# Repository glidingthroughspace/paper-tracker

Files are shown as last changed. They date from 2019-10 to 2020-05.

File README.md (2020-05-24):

# Paper Tracker

The Paper Tracker is a system for tracking documents inside buildings. It uses WiFi Access Points to
calculate the documents' current location and links it to the current step in its workflow.

It consists of a hardware tracker, a backend server and a mobile application for Android and iOS.

## Getting started

You need to get a Tracker (the hardware device), install the backend application on a server and
download the app for your phone.

### The Server

Download the pre-built server application for
[Linux](https://github.com/glidingthroughspace/paper-tracker/releases/latest/download/paper-tracker_linux_x86_64),
place it on a server and run it. It will listen for HTTP requests on port `8080`, so go ahead and
visit `your-server.domain:8080`, which links all the other downloads you'll need.

Note that the server also listens for CoAP requests on port `5688`, so you might need to allow UDP
requests to that port in your servers firewall.

You could also install [Go](https://go.dev) and build the server yourself by running `make` or `make
run` in the `server/` directory. This way, you can run the server on Windows and MacOS as well.

Additionally there is a Dockerfile available in the `server` folder. The docker also uses `8080` as http and `5688` as CoAP port default.
The config file and database are located in the `/config` folder.

For individually configuring the server, you can use the `config_example.toml` as template and rename it to `config.toml`.
Information about the available parameters are available through the `--help` command of the server executable.

### The Tracker

The tracker is built out of a [TinyPICO](https://tinypico.com), which is an ESP32-based development
board and a LiPo battery.
If you have a Tracker, download the Firmware Flasher for
[Linux](https://github.com/glidingthroughspace/paper-tracker/releases/latest/download/flasher-Linux.zip)
or
[Windows](https://github.com/glidingthroughspace/paper-tracker/releases/latest/download/flasher-Windows.zip),
extract the ZIP file and run the flasher application. It will ask you for WiFi credentials and a
path to the firmware directory, which is bundled in the given ZIP file. For flashing, you'll need to
have [PlatformIO Core](https://platformio.org) installed.
After flashing the tracker, it will automatically connect to the server, if the given WiFi
credentials are correct.

### The App

The app is written in Flutter and thus is available for Android and iOS. However, prebuilt apps only
exist for Android. You can download them from Github Releases, an explanation of which download
you'll need is given on the server's download page.

# Licensing

This repository contains multiple sub-projects (folders), each of which has its
own `LICENSE` file, denoting which license is used for the specific
sub-project. The TL;DR is: Code is licensed under the [Apache
2.0](https://www.apache.org/licenses/LICENSE-2.0.html) license, the paper
(everything in the `paper/` directory) is under the
[CC-BY-NC-SA 4.0](http://creativecommons.org/licenses/by-nc-sa/4.0/)
license.

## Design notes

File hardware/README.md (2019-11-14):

# Hardware

This directory contains the firmware for the tracker devices as well as everything else related to
the hardware like CAD files or analyses.

See the README files in each directory for more information.

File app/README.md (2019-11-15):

# paper_tracker

Frontend application for the paper-tracker project

## Getting Started

This project is a starting point for a Flutter application.

A few resources to get you started if this is your first Flutter project:

- [Lab: Write your first Flutter app](https://flutter.dev/docs/get-started/codelab)
- [Cookbook: Useful Flutter samples](https://flutter.dev/docs/cookbook)

For help getting started with Flutter, view our
[online documentation](https://flutter.dev/docs), which offers tutorials,
samples, guidance on mobile development, and a full API reference.

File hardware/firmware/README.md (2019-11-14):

# Tracker Firmware

This directory contains the firmware for the paper tracker hardware devices.
It is built using [PlatformIO](https://platformio.org), which makes it simple to resolve
dependencies and build it in a CI workflow.

Since the hardware is supposed to be based on an ESP8285 board, this is one of the build targets.
Currently however, we're developing the firmware on the 100% compatible ESP8266 board, namely a
WeMos D1 mini, which is the default build target.

We build the firmware using `make`, since the PlatformIO commands can get quite long. The following
targets are available:

* `build`: Build for the _current_ MCU platform. You can set the platform in the
  `PLATFORM` variable (either `d1_mini` or `esp8285`)
* `build-all`: Build for all defined platforms. This is used in CI
* `upload`: Uploads the code to the current platform. Configure the serial port to use in the
  `SERIALPORT` variable (defaults to `/dev/ttyUSB0`)
* `monitor`: Starts the serial monitor on the given serial port
* `run`: Build and upload the code, start the serial monitor

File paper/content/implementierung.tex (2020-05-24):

\chapter{Implementierung} \label{chap:implementierung}

\section{Hardware und Firmware}

Im Folgenden wird erläutert, wie der Tracker hinsichtlich der verwendeten Hardware und der
entsprechenden Firmware implementiert wurde.

\subsection{Verwendete Technologien}\label{sec:hardware-used-technologies}

Als Mikrocontrollerplattform wurde die sogenannte \enquote{TinyPICO}-Plattform gewählt. Nach eigener
Aussage handelt es sich dabei um die kleinste vorgefertigte Entwicklungsplattform basierend auf
Mikrocontrollern vom Typ ESP32. (vgl. \cite{tinypico2020}) Dieser Aspekt ist für die Erfüllung von \ref{nf:klein} wichtig.
Dieser Mikrocontroller wurde gewählt, da er alle benötigten Funktionen wie beispielsweise \gls{WLAN}
bereits über ein \gls{API} bereitstellt.

Die TinyPICO-Entwicklungsplattform stellt neben dem Mikrocontroller weitere Hardware bereit, so sind
unter anderem
eine Stromversorgung über \gls{USB} sowie Lithium-Polymer-\gls{Akku}, ein Übersetzer von \gls{USB}
zu \gls{UART} zur Programmierung des Mikrocontrollers und eine Vollspektrum-\gls{LED} verbaut.
Ein weiterer Vorteil ist das bereits integrierte Ladesystem, welches einen angeschlossenen
Lithium-Polymer-\gls{Akku} automatisch auflädt, sobald der Tracker über \gls{USB} mit einer
Stromquelle verbunden wird. Außerdem können über das Ladesystem der aktuelle Ladezustand und die
Spannung des \glspl{Akku} abgefragt werden, was für die Erfüllung von \ref{fa:benachrichtigung}
unabdingbar ist.

Die Firmware wurde in der Programmiersprache C++ auf Basis des Arduino-Frameworks erstellt. Dieses
Framework wurde gewählt, da es auf vielen Plattformen, wie auch dem ESP32 lauffähig ist, weit
verbreitet ist und somit viele Bibliotheken für das Framework existieren.

Das \enquote{Flasher}-Tool zum Programmieren und Konfigurieren der Firmware wurde in Python
entwickelt.
Der Grund dafür liegt in der Möglichkeit sehr schnell und simpel sowohl ein Programm als auch eine \gls{GUI}
programmieren zu können.
Dies wird durch die Bibliothek \enquote{PySimpleGUI} ermöglicht, die lediglich mit einer groben Layout-Beschreibung
eine Oberfläche zusammenstellt.
Alle weiteren benötigten Bibliotheken sind in der Python-Standardbibliothek enthalten.
Vor allem ist hierbei die \enquote{multiprocessing}-Bibliothek wichtig, mit welcher andere Programme aufgerufen werden können.
Um aus dem enstandenen Python-Skript eine ausführbare Datei für die verbreitesten Betriebssysteme zu erstellen, wird \enquote{PyInstaller} verwendet.
Die daraus enstehende Datei beinhaltet bis auf das PlatformIO-Tooling alle benötigten Ressourcen.

\subsection{Flasher}
Aufgrund der angestrebten Einfachheit dieses Programmes besteht es aus insgesamt nur drei Dateien.
Der Hauptbestandteil des Flashers ist das eigentliche Python-Skript.
Zusätzlich wird die Datei \enquote{requirements.txt} benötigt, welche alle Bibliotheken für den
Bibliotheksmanager \enquote{pip} auflistet.
In dieser Datei sind lediglich, wie oben erwähnt, \enquote{pysimplegui} und \enquote{pyinstaller} aufgeführt.
Die dritte und letzte Datei ist ein \enquote{Makefile}, welches einige Befehle zum Installieren der Bibliotheken,
Ausführen des Skripts oder Erstellen der ausführbaren Datei bereitstellt.

Das Skript selbst beginnt nach dem Importieren der benötigten Bibliotheken mit dem Parsen der
Kommandozeilenargumente.
Möglich ist nur das Argument \texttt{--keep-credentials}.
Das Skript erzeugt eine Datei, in welcher die Zugangsdaten für das vom Tracker zu verwendende
\gls{WLAN}-Netzwerk sowie weitere potentiell sensitive Informationen enthalten sind. Im
Standardfall wird diese Datei nach dem Erstellen der Firmware und der Programmierung des Trackers
gelöscht. Ist das Kommandozeilenargument \texttt{--keep-credentials} gegeben, wird die Datei nach
erfolgreichem Abschluss des Programmiervorganges nicht gelöscht, was vor allem in der
Entwicklungsphase der Software vorteilhaft ist.

Weiter werden einige Konstanten definiert.
Diese sind zum einen der Titel des Programm-Fensters und einige sogenannte \enquote{Keys},
die eindeutig bestimmte Elemente der \gls{GUI} identifizieren.

Nach den Konstanten werden drei Funktionen definiert, die die eigentliche Logik des Flashers beinhalten.
Zuerst eine Funktion, die alle möglichen Ports, über die ein Tracker programmiert werden kann, auflistet.
Dies wird über ein Aufrufen von PlatformIO ermöglicht: \enquote{pio device list}.

Die nächste Funktion generiert die für die Firmware benötigte Datei mit der Konfiguration des Trackers.
Sie liest ein Template mit Platzhalter-Werten der Datei ein und ersetzt die Platzhalter mit den eingegebenen Werten, die als Parameter übergeben werden.
Nach dem Einsetzen der Werte wird die Datei geschrieben.
Der Pfad, an dem sich die Firmware befindet, ist auch Teil der Werte, die als Parameter übergeben werden.
Zugriff auf einen einzelnen Wert wird über die oben erwähnten konstanten \enquote{Keys} ermöglicht.

In der letzten Funktion wird das Programmieren an sich ausgeführt.
Auch diese Funktion bekommt die eingebenenen Werte als Parameter. Aus diesen wird der ausgewählte Port benötigt.
Mit diesem wird wieder PlatformIO aufgerufen: \enquote{pio run -e tinypico -t upload --upload-port port}.

Vor dem Hauptteil des Skripts werden noch die Layouts für die \gls{GUI} benötigt.
Es werden zwei verschiedene Layouts definiert: Ein Eingabe-Layout und ein Programmier-Layout.
Das Eingabe-Layout ist in \autoref{fig:flasher-input} dargestellt.
Es ist eine Tabelle aus Eingabe-Feldern mit Erklärungen, in denen alle benötigten Konfigurationen eingetragen werden können.
Die Eingabe-Felder selbst sind mit den Keys verknüpft.
Am unteren Teil des Layouts befindet sich ein Button, der das Programmieren startet.

\begin{figure}[htbp]
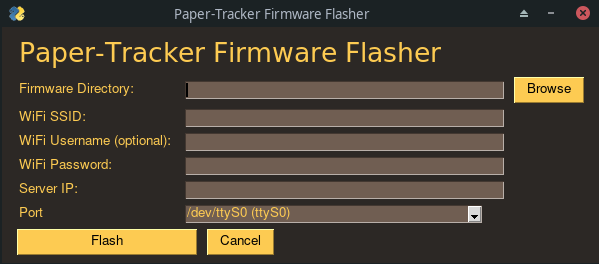
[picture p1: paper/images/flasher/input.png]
	
	\centering
	\caption{Layout des Eingabe-Fensters}
	\label{fig:flasher-input}
\end{figure}

Das Programmier-Layout besteht lediglich aus einem Titel, einem Textfeld und einem Button.
Es ist in \autoref{fig:flasher-flash} dargestellt.
Im Textfeld soll der aktuelle Status angezeigt werden.
Der Button ist zum Schließen des Programms, sobald der Vorgang abgeschlossen ist.

\begin{figure}[htbp]
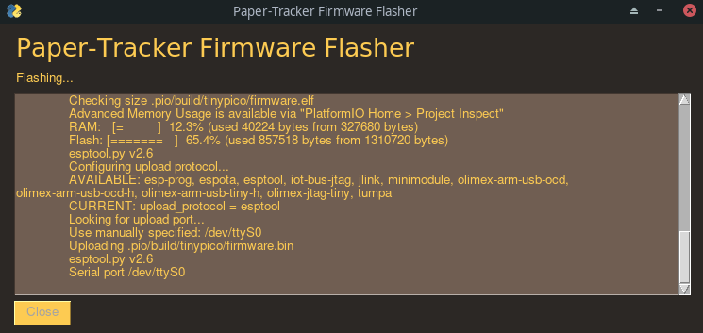
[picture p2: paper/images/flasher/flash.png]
	
	\centering
	\caption{Layout des Programmier-Fensters}
	\label{fig:flasher-flash}
\end{figure}

Im Hauptteil des Skripts wird nun zuerst das Fenster mit dem Eingabe-Layout geöffnet.
Sobald der Button zum Start gedrückt wurde, werden die eingegebenen Werte ausgelesen.
Das Eingabe-Fenster wird geschlossen und das Programmier-Fenster mit dem entsprechendem Layout geöffnet.
Ist dieses offen, wird die Funktion zum Generieren der Konfigurationsdatei und die Funktion zum Programmieren des Trackers aufgerufen.
Im Textfeld des Layouts werden diese Schritte entsprechend dokumentiert.
Auch die Ausgabe des Programmierens wird im Textfeld abgebildet.
Nach dem Programmieren wird, je nach Kommandozeilenargument, die generierte Datei gelöscht.
Nun kann das Fenster und damit das gesamte Programm über den Schließen-Button geschlossen werden.

Tritt während dieses gesamten Vorgang ein Fehler auf, wird dieser entsprechend aufgefangen und die Fehlermeldung im Textfeld angezeigt.
Das Löschen der generierten Datei wird auch im Fehlerfall ausgeführt.

\subsection{Akkumulator}

Um \ref*{nf:akku} zu erfüllen, muss ein \gls{Akku} mit entsprechend großer Kapazität gewählt werden.
Zu diesem Zweck wird die Laufzeit des Trackers mit einem \gls{Akku} mit einer Kapazität von $850
mAh$ in verschiedenen Szenarien gemessen. Bei den Tests befindet sich der Tracker dauerhaft im
\enquote{Tracking}-Status, meldet also immer wieder die aktuelle Position an den Server. Dieser
Zustand wurde gewählt, da hier der Stromverbrauch am größten ist. Zu beachten ist jedoch, dass der
Tracker pro Zyklus (Aufwachen und Abholen eines Kommandos) immer nur einmal die \gls{WLAN}-Umgebung an den Server übermittelt. Wie in
\autoref{sec:tracker-lokalisierung} beschrieben, ist dies noch nicht unbedingt ausreichend, um den
Tracker zu lokalisieren.

Im ersten Test, dessen Ergebnis in
\autoref{fig:battery-runtime-quicktrack} in blau zu sehen ist, wurde dabei alle $10$ Sekunden die Position
des Trackers abgefragt.

\begin{figure}[htbp]
	\centering
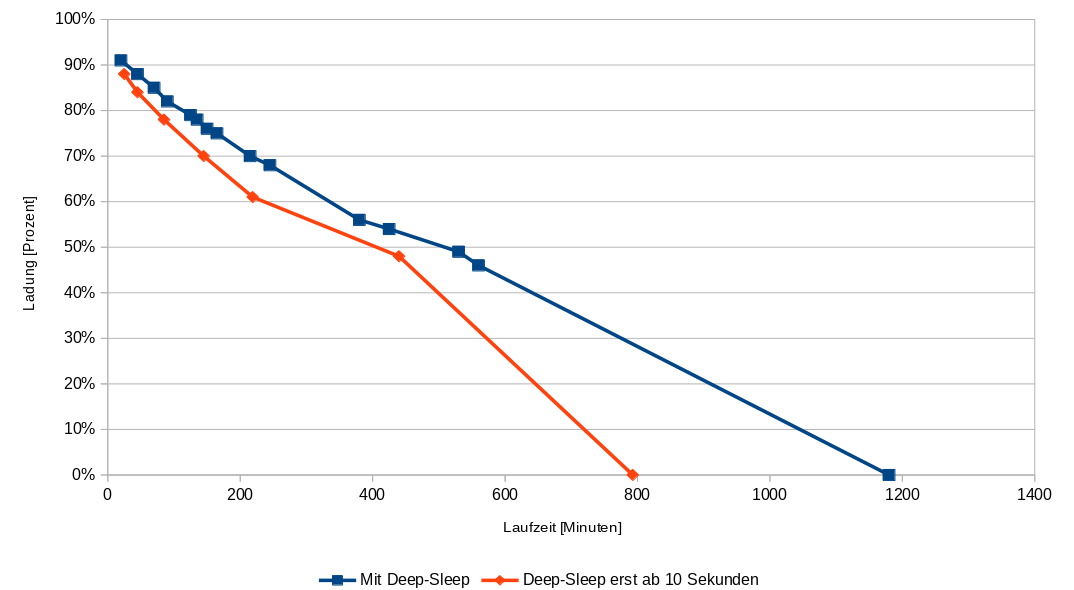
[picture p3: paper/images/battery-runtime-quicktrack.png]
	
	\caption{Akkulaufzeit mit einem Tracking-Intervall von 10 Sekunden}
	\label{fig:battery-runtime-quicktrack}
\end{figure}

Beim ersten Test ist der Tracker nach dem Bearbeiten einer Aufgabe direkt in den \enquote{Deep-Sleep}
übergegangen. Beim zweiten Test (dargestellt in rot) erst dann, wenn die vom Server übermittelte Schlafdauer größer als $10$
Sekunden ist, was in diesem Test nie der Fall war. Wie deutlich zu sehen ist, kann durch das
sofortige Schlafen des Trackers eine um circa $400$ Minuten längere Laufzeit erreicht werden. Es ist
jedoch zu erwarten, dass der Tracker immer länger als $10$ Sekunden schläft, außer beim Einlernen
eines neuen Raumes. Bei dieser Operation ist vor allem die Reaktivität des Trackers wichtig, um
möglichst viele \glspl{AP} mit möglichst vielen Messungen zu erfassen. Daher wird die
Funktionalität, dass der Tracker sich nur in den \enquote{Deep-Sleep} begibt, wenn die Schlafdauer
$10$ Sekunden überschreitet, implementiert und die damit verbundene, geringere Laufzeit in Kauf
genommen.

\begin{figure}[htbp]
	\centering
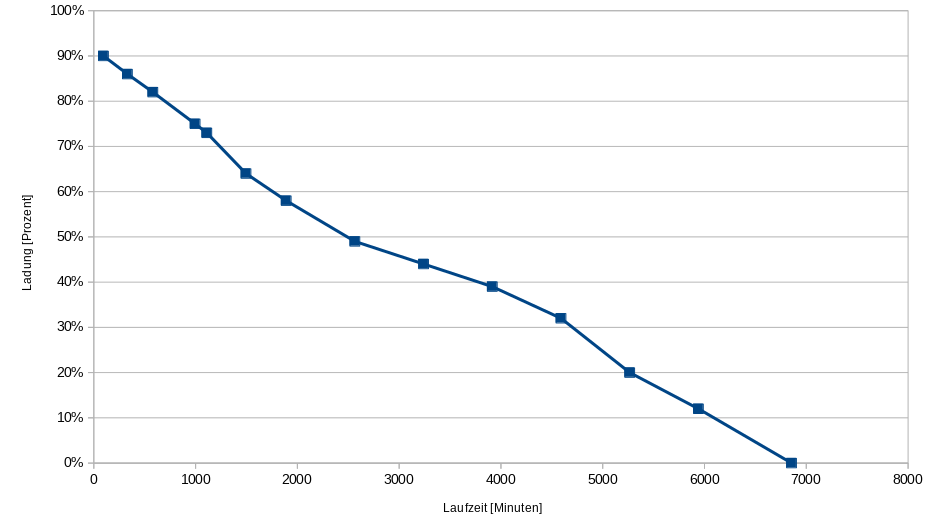
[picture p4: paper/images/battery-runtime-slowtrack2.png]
	
	\caption{Akkulaufzeit mit einem Tracking-Intervall von 60 Sekunden}
	\label{fig:battery-runtime-slowtrack}
\end{figure}

In einem zweiten Szenario ist der Tracker alle $60$ Sekunden aufgewacht, um die aktuelle Position
zu ermitteln. Die Laufzeit des Trackers mit diesen Parametern ist in
\autoref{fig:battery-runtime-slowtrack} zu sehen. Wie zu sehen ist, skaliert die Laufzeit des
Trackers nahezu linear mit der Schlafdauer. Mit einer Schlafdauer von $60$ Sekunden konnte bereits
eine Laufzeit von mehr als 4 Tagen erreicht werden.

Daraus lässt sich schließen, dass sich \ref*{nf:akku} mit einem \gls{Akku} mit einer Kapazität von $850
mAh$ erfüllen lässt, indem der Tracker nicht den gesamten Tag aktiv ist oder das Tracking-Intervall
auf $120$ Sekunden erhöht wird. Da Dokumente üblicherweise nicht den gesamten Tag über getracked
werden müssen, sondern nur in den üblichen Arbeitszeiten, wird die Möglichkeit in den Server
implementiert, ebendiese zu definieren. So kann der Tracker meist den halben Tag inaktiv sein, am
Wochenende muss er gar nicht aufwachen.

\subsection{Sammeln von \glsentryshort{WLAN}-Daten}

Um die aktuelle \gls{WLAN}-Umgebung abzurufen und an den Server zu senden wird primär in das
Arduino-Framework eingebaute Funktionalität genutzt. Die durch das Framework bereitgestellte Klasse
\texttt{WiFi} bietet Methoden zur Abfrage aller \glspl{AP} inclusive deren \gls{BSSID},
\gls{SSID} und \gls{RSSI}.

\begin{lstlisting}[caption={Ausschnit aus der Firmware des Trackers -- Abrufen der \glsentryshort{WLAN}-Netzwerke},label={lst:wlan-firmware}]
std::vector<ScanResult> WIFI::getAllVisibleNetworks() {
  uint8_t visibleNetworkCount = WiFi.scanNetworks();
  std::vector<ScanResult> scanResults(0);
  for (auto i = 0; i < visibleNetworkCount; i++) {
    scanResults.emplace_back(WiFi.RSSI(i), WiFi.BSSIDstr(i), WiFi.SSID(i));
  }
  return scanResults;
}
\end{lstlisting}

In \autoref{lst:wlan-firmware} ist zu sehen, wie die Standardbibliothek genutzt wird. Die hier
erstellte Liste von Scanergebnissen wird, bevor sie zum Server gesendet wird, in mehrere Teile
geteilt. Diese enthalten jeweils fünf Scanergebnisse, damit die in
\autoref{sec:tracker-lokalisierung} beschriebene, maximale Größe eines \gls{UDP}-Paketes nicht
überschritten wird.

Die Arduino-\gls{API} gibt für die \texttt{WiFi.RSSI()}-Funktion an, dass diese eine Angabe in $dBm$
zurückliefert. (vgl. \cite{Arduino2020.1}) Durch diese Standardisierung kann jede
Entwicklungsplattform genutzt werden, die mit dem Arduino-Framework kompatibel ist, ohne dass die
Messung angepasst werden muss.

\subsection{\glsentryshort{API}-Client}

Um sich mit der vom Server angebotenen \gls{CoAP}-\gls{API} zu verbinden, wurde in der Firmware ein
entsprechender Client implementiert. Dieser nutzt eine erweiterte Version der \enquote{CoAP simple
library}\footnote{Original: \url{https://github.com/hirotakaster/CoAP-simple-library}} für die
Arduino-Plattform. Diese implementiert die Kommunikation mit einem \gls{CoAP}-Server, indem sie
Methoden zur Verfügung stellt, um Anfragen an einen Server zu senden und Antworten zu empfangen.

Die Klasse \texttt{APIClient}, welche in der Firmware genutzt wird, um die Kommunkation zu kapseln,
arbeitet mit Callbacks, um Antworten an Anfragen an den Aufrufer zurückzugeben. Dabei wird auch ein
Timeout-Mechanismus implementiert, welcher Anfragen abbricht, wenn für eine gewisse Zeit keine
Antwort empfangen wird. Dadurch wird verhindert, dass aufgrund der volatilen Natur von \gls{UDP} der
Tracker beliebig lange auf Antworten wartet und so sehr schnell den \gls{Akku} entleert.

Zusätzlich kümmert sich der \gls{API}-Client um die Serialisierung und Deserialisierung von
Nutzdaten in das \gls{CBOR}-Format.

\subsection{Serialisierung und Deserialisierung}

Wie in \autoref{par:tracker-schnittstelle} beschrieben, werden Nutzdaten zwischen Server und Tracker
mit \gls{CBOR} codiert ausgetauscht. Dieses Format ist besonders performant und leichtgewichtig und
daher optimal für den Einsatz im \gls{IoT} geeignet. Implementiert wurde ein System zur
Serialisierung und Deserialisierung auf Basis der \enquote{libCBOR}-Bibliothek \footnote{Siehe
\url{https://github.com/ssilverman/libCBOR}}. Das entwickelte System ermöglicht es, sehr schnell und
einfach Entitäten zu \gls{CBOR} zu serialisieren und zu deserialiseren.

\begin{lstlisting}[caption={Beispiel zur Deserialisierung von \glsentryshort{CBOR} mit den
entwickelten Helferklassen},label={lst:cbor-deserialiserung}]
class Command {
private:
	CBORUint16 sleepTimeSec{"sleep_time_sec"};
	CBORUint8 type{"type"};
public:
	bool fromCBOR(uint8_t* buffer, size_t bufferSize) {
		auto cbor = CBORParser(buffer, bufferSize);
		if (!cbor.isWellformedModel()) { return false; }

		while(cbor.advance()) {
			auto key = cbor.findNextKey();
			if (key == nullptr) { continue; }

			if (type.matchesKey(key)) {
				type.deserializeFrom(cbor);
			} else if (sleepTimeSec.matchesKey(key)) {
				sleepTimeSec.deserializeFrom(cbor);
			}
		}

		return true;
	}
};
\end{lstlisting}

So ist in \autoref{lst:cbor-deserialiserung} der vollständige, zur Deserialisierung eines Befehls
vom Server an den Client nötige Code gezeigt. Einzig die Fehlerbehandlung wurde zur
Übersichtlichkeit entfernt. Für die Implementierung der Bibliothek wurden eigene Typen entwickelt,
die Basisdatentypen wiederspiegeln (\texttt{CBORUint8}, \texttt{CBORInt16}, \texttt{CBORString},
...) und die Serialisierung und Deserialisierung in sich kapseln.

\section{Backend-Server}

\subsection{Verwendete Technologien} \label{sec:impl-server-technology}

Die grundlegend verwendete Technologie für den Backend-Server ist die Programmiersprache \enquote{Go}.
Go wurde ausgewählt, da es eine einfach zu verstehende Programmiersprache ist, die optimiert für Server-Anwendungen ist (vgl. \cite{Weigend2019}).
Zudem sind alle am Projekt beteiligten Personen schon mit der Sprache vertraut.

Go stellt eine gute Standardbibliothek zur Verfügung, die an vielen Stellen verwendet wird.
Trotzdem werden zusätzlich einige externe Bibliotheken verwendet.
Diese dienen hauptsächlich dazu, die externen Schnittstellen (\gls{HTTP} und \gls{CoAP}) mit den dazugehörigen Datenformaten zur Verfügung zu stellen.
Auch werden Bibliotheken für ein einfacheres Testing verwendet.

Im Folgenden sind die verwendeten Bibliotheken aufgelistet:
\begin{description}
	\item[pflag (https://github.com/spf13/pflag)] \hfill \\
		\enquote{pflag} wird zum Angeben und Parsen von Kommandozeilenargumenten verwendet. Es ist kompatibel mit \enquote{viper}.
	\item[viper (https://github.com/spf13/viper)] \hfill \\
		Für die Konfiguration des Servers wird \enquote{viper} verwendet. Es kann Konfigurationen aus \enquote{pflag}, Dateien und mehr einlesen.
	\item[logrus (https://github.com/sirupsen/logrus)] \hfill \\
		\enquote{logrus} ist ein strukturiertes Logging-Tool, das für jegliche Logs innerhalb des Servers verwendet wird.
	\item[gorm (https://github.com/jinzhu/gorm)] \hfill \\
		\enquote{gorm} ist ein \gls{ORM} Framework, das die Datenbankanbindung für den Server zur Verfügung stellt.
	\item[Gin (https://github.com/gin-gonic/gin)] \hfill \\
		\enquote{Gin} ist ein HTTP Framework, das Routing, Parameter-Matching, etc. übernimmt. Zudem kann es standardmäßig \gls{JSON} verstehen.
	\item[go-coap (https://github.com/go-ocf/go-coap)] \hfill \\
		\enquote{go-coap} ist ein \gls{CoAP} Framework, das hauptsächlich das Routing übernimmt. Einige weitere Aufgaben, die z.B. \enquote{Gin} übernimmt, müssen selbst programmiert werden.
	\item[go-codec (https://github.com/ugorji/go)] \hfill \\
		\enquote{go-codec} stellt die Codierung für \gls{CBOR} zur Verfügung.
	\item[now (https://github.com/jinzhu/now)] \hfill \\
		\enquote{now} stellt Hilfsfunktionen für Zeitberechnungen zur Verfügung.
	\item[stats (https://github.com/montanaflynn/stats)] \hfill \\
		\enquote{stats} stellt einige mathematische Funktionalitäten für statistische Berechnungen zur Verfügung.
	\item[xlsx (https://github.com/tealeg/xlsx)] \hfill \\
		Mit \enquote{xlsx} können Dateien im \gls{XLSX} Dateiformat erstellt, bearbeitet und gelesen
		werden. Im Server wird sie für das Erstellen des Excel-Exports genutzt.
	\item[gomail (https://github.com/go-gomail/gomail)] \hfill \\
		\enquote{gomail} wird verwendet, um E-Mails verschicken zu können.
	\item[ginkgo (https://github.com/onsi/ginkgo)] \hfill \\
		Mit \enquote{ginkgo} können Tests in \gls{BDD} Technik geschrieben werden.
	\item[gomega (https://github.com/onsi/gomega)] \hfill \\
		\enquote{gomega} ist eine Matching Library, die zu \enquote{ginkgo} gehört. Sie stellt Vergleiche zwischen erwarteten Werten und tatsächlichen Werten zur Verfügung.
	\item[GoMock (https://github.com/golang/mock)] \hfill \\
		\enquote{GoMock} ist ein Mocking Framework, das für verschiedene Tests verwendet wird.
\end{description}

Als Datenbank wird in Kombination mit \enquote{gorm} eine \enquote{SQLite} verwendet.
Der große Vorteil ist, dass eine SQLite Datenbank eine einfache Datei ist und kein externer Server aufgesetzt werden muss.
Dies vereinfacht vor allem die Entwicklung.
Zum Beispiel ist ein einfaches Zurücksetzen der Daten durch ein Löschen der Datei möglich.

In einem späteren Einsatz des Paper-Trackers können dank der \enquote{gorm} Bibliothek auch andere
Datenbanken verwendet werden, die eher für einen dauerhaften und sichereren Einsatz vorgesehen sind.
Möglich sind dafür \enquote{MySQL}, \enquote{PostgreSQL}, \enquote{Microsoft SQL Server} und wie erwähnt SQLite.
Im Code des Servers muss hierfür lediglich eine erweiterte Konfiguration ermöglicht werden. (vgl. \cite{Jinzhu2020})

\subsection{\glsentryfull{REST}-Schnittstelle}

Die \gls{REST}-Schnittstelle zur Anbindung der App wurde wie in \autoref{par:app-schnittstelle}
beschrieben implementiert.
Dabei wurden alle Endpunkte entsprechend umgesetzt.
Wie in \autoref{sec:impl-server-technology} erwähnt, wird das Gin-Framework als
\gls{HTTP}-Router und zum Serialisieren sowie Deserialisieren der Nutzdaten verwendet.
Das Framework ermöglicht es, für jeden \gls{REST}-Endpunkt, also für jede Kombination aus
\gls{HTTP}-Verb und \gls{URL} eine sogenannte Handler-Funktion zu definieren. Diese wird aufgerufen,
wenn eine Anfrage an die entsprechende Ressource getätigt wird. Die Handler-Funktionen parsen
zunächst die Anfragedaten in entsprechende Go-Strukturen. Im Anschluss werden eine oder mehrere
Manager-Funktionen aufgerufen, welche die Geschäftslogik enthalten. Das Ergebnis dieses Aufrufes
wird dann von der Handler-Funktion in das Zielformat, in diesem Fall \gls{JSON}, serialisiert und an
den Aufrufer gesendet.

\subsection{\glsentryfull{CoAP}-Schnittstelle}

Die \gls{CoAP}-Schnittstelle für die Tracker wurde grundsätzlich wie in
\autoref{par:tracker-schnittstelle} beschrieben implementiert. Es wurde allerdings ein weiterer
Endpunkt hinzugefügt: Über den Pfad \texttt{/tracker/status}, welcher mit dem Verb \texttt{POST}
angesprochen wird, kann der Tracker aktuelle Statuswerte, wie beispielsweise die aktuelle
Akkuladung, an den Server übermitteln. Diese Statuswerte werden bei aktivem Tracking in den
Scanergebnis-Paketen übermittelt. Wenn der Tracker sich jedoch im Leerlauf befindet, sendet der
Server periodisch Status-Kommandos an den Tracker, sodass auch hier der Ladezustand des \gls{Akku}s, sowie
die verbleibende Restladung aktualisiert werden können.

\subsection{Tracker-Lokalisierung} \label{sec:tracker-lokalisierung}

Wie in \autoref{sec:tracking-hardware} beschrieben, wird die Lokalisierung der Tracker mit einem
Score-basierten System durchgeführt.

Dazu werden zunächst Scanergebnisse vom jeweiligen Tracker gesammelt und dann ausgewertet. Da die
Datengröße der Scanergebnisse je nach Anzahl der vom Tracker sichtbaren \gls{WLAN}-Netzwerke zu
groß für ein einzelnes \gls{UDP}-Paket ist\footnote{Im Arduino-Framework gibt es eine
Limitierung von 1446 Bytes für die Größe eines \gls{UDP}-Paketes. (vgl. \cite{Arduino2020})}, wurde
das \gls{API} so gestaltet, dass die Ergebnisse in mehreren Paketen an den Server übermittelt werden
können. Dazu berechnet der Tracker im Voraus, in wie viele Pakete die Scanergebnisse geteilt werden
müssen. Diese Zahl, sowie eine für den Ergebnissatz einheitlicher, zufällig erzeugter \gls{ID} sind
jedem Teilpaket angehängt. So kann der Server erkennen, ob alle Ergebnisse empfangen wurden und
diese dann verwenden. Dass nicht alle Pakete eines Ergebnissatzes beim Server angekommen sind, ist
dadurch erkennbar, dass eine andere \gls{ID} empfangen wird. In diesem Fall werden alle vom
vorherigen Paket empfangenen Scanergebnisse verworfen und die neuen Pakete gespeichert.
\TODO{Das hier kann vielleicht zu CoAP-Schnittstelle verschoben werden}

Sobald ein vollständiger Ergebnissatz empfangen wurde, wird aus diesem ein Score für jeden Raum
ermittelt. Dieser Score ist eine Zahl, deren Wert größer wird, je besser die gemessene
\gls{WLAN}-Umgebung mit der gelernten übereinstimmt.

\begin{lstlisting}[caption={Pseudocode-Beschreibung der Scoring-Funktion},label={lst:scoring},tabsize=2]
# Berechnet den Score für ein Scanergebnis und einen Raum
#
# rssi ist das aktuelle Scanergebnis des Trackers
# room enthält die zuvor gelernten Scandaten
func getScoreForScanResultAndRoom(rssi, room) float {
	score := 0.0
	rssiFactor := math.Abs(rssi / 100.0)

	if rssi <= room.Maximum && rssi >= room.Minimum {
		score += inMinimumMaximumFactor * rssiFactor
	}
	if rssi < room.ThirdQuartile && rssi > room.FirstQuartile {
		score += inQuartilesFactor * rssiFactor
	}
	if isInRange(rssi, room.Mean, rangeForMean) {
		distance := math.Abs(room.Mean - rssi)
		score += math.Abs(distance-rangeForMean) * inMeanRangeFactor * rssiFactor
	}
	if isInRange(rssi, room.Median, rangeForMedian) {
		distance := math.Abs(room.Median - rssi)
		score += math.Abs(distance-rangeForMedian) * inMedianRangeFactor * rssiFactor
	}
	return score
}
\end{lstlisting}

\autoref{lst:scoring} zeigt einen Teil des Scoring-Algorithmus. Dieser Teil wird für jeden Raum und
jedes Scanergebnis ausgeführt. In den vier \texttt{if}-Zweigen werden jeweils Punkte dafür vergeben,
dass das Scanergebnis in einem bestimmten Bereich liegt. Die Zweige sind nach ihrer Signifikanz
geordnet. So wird ein Scanergebnis, welches im Bereich des vorher gelernten Minimums und Maximums
liegt, mit wenigen Punkten \enquote{belohnt}, während es viele Punkte bekommen kann, wenn es sehr
nahe am arithmetischen Mittel liegt.

Die genaue Punkteverteilung ist konfigurierbar, um den Algorithmus möglichst offen für
unterschiedliche \gls{WLAN}-Umgebungen zu machen. Die Standardwerte der Parameter
\texttt{inMinimumMaximumFactor}, \texttt{inQuartilesFactor}, \texttt{inMeanRangeFactor} und
\texttt{inMedianRangeFactor} wurden experimentell für das \gls{WLAN}-Netz der \gls{DHBW} ermittelt und liegen
bei $1$, $5$, $5$ und $5$.

Zu beachten ist, dass ein Einschluss in Minimum/Maximum und erstem und drittem Quartil dem
Scanergebnis eine fixe Punktzahl gewährt, während beim Median und Mittel jeweils mit Abständen
kalkuliert wird. So bekommt ein Ergebnis, welches näher an einem der beiden Werte liegt, eine
größere Punktzahl. Die Punktzahl skaliert dabei linear zum Abstand.

Der \texttt{rssiFactor} in Zeile 7 wird verwendet, um weiter entfernte \glspl{AP} weniger in die
Berechnung mit einfließen zu lassen. Da die von den Trackern ermittelte \gls{RSSI} nicht exakt ist
und oft auch ohne ein Bewegen des Trackers um wenige $dBm$ schwankt, wird so verhindert, dass eine
Schwankung von beispielsweise $-80dBm$ auf $-82dBm$ die gleiche Auswirkung hat, wie eine gleichgroße
Schwankung eines \gls{AP}s mit deutlich besserem Empfang.

Die Scores für jede \gls{BSSID}, also auch für jedes Scanergebnis, werden dann pro Raum addiert,
wobei eine eingelernte \gls{BSSID}, für welche kein Scanergebnis existiert, mit $-10$ Punkten
\enquote{bestraft} wird. Nun liegt für jeden Raum ein Gesamt-Score vor, anhand dessen der passendste
Raum ausgewählt werden kann. Dies ist der Raum mit dem größten Score.

Aufgrund der bereits beschriebenen Schwankungen beim Scannen der \glspl{AP} wird dieses Scoring
jedoch mehrfach (Standardfall: dreifach) durchgeführt und der beste Raum anhand des arithmetischen
Mittels der Scores ausgewählt. Dies verlängert einen Lokalisierungsvorgang pro Messung um etwa
$5-15$ Sekunden, was allerdings kein Problem ist, da die Lokalisierung nicht in Echtzeit
durchgeführt werden muss.

Damit kein Raum ausgewählt wird, in dem der Tracker nicht liegt, muss jeder Raum einen Schwellwert
erreichen, um in die Auswahl aufgenommen zu werden. Dieser Schwellwert ist auf $600$ gesetzt, was im
Umfeld der \gls{DHBW} zu guten Ergebnissen geführt hat. Dieser Wert ist jedoch, wie die restlichen
Scoring-Parameter, durch den Nutzer konfigurierbar.

\subsection{Daten-Export}

In diesem Kapitel wird die Implementierung des Datenexports in eine Excel-Datei näher erläutert.
Dieser besteht aus größtenteils zwei Unterpunkten: Dem Sammeln und Aufbereiten der Daten für den
Export und das Schreiben der Excel-Datei selbst.
Beides wird zusammengefasst im \enquote{ExportManager} durchgeführt.

Um die Daten für den Export zu sammeln, nutzt der \enquote{ExportManager} einige andere Manager:
\enquote{WorkflowTemplateManager}, \enquote{WorkflowExecManager} und \enquote{RoomManager}.
Über diese können alle benötigten Daten abgefragt werden.
Zuerst werden alle Templates abgefragt.
Für jedes Template werden alle verfügbaren Ausführungen des Templates angefordert.
Weiter wird für jeden Schritt in einem Template/einer Ausführung Informationen über die Schritte und die den Schritten
zugewiesenen Räume abgefragt.
Während die Daten gesammelt werden, werden auch einige Metriken erfasst: Die Anzahl Ausführungen pro Template,
wie viele Ausführungen beendet wurden und wie lange eine durchschnittliche Ausführung gebraucht hat.

Nachdem alle grundlegenden Daten gesammelt wurden, wird nochmals durch alle Templates iteriert und diese nach Revisionen sortiert.
Dies bedeutet, dass alle Templates zusammen gruppiert werden, die die gleiche ursprüngliche Revision haben.
Die ursprüngliche Revision selbst wird auch mit gruppiert.
Damit sind alle Daten entsprechend gesammelt und aufbereitet, um exportiert zu werden.

Für den Export selbst wird, wie schon in \autoref{sec:impl-server-technology} angemerkt, die Bibliothek \enquote{xlsx} verwendet.
Die Entscheidung, diese Bilbiothek zu nutzen, wurde getroffen, da sie eine simple Schnittstelle hat und regelmäßig aktualisiert wird
(Stand 20. April 2020: Letzte Aktualisierung vor 24 Tagen \cite{tealeg2020}).

\enquote{xlsx} arbeitet mit Pointern auf Objekte verschiedener Typen, die jeweils ein Objekt in Excel wiederspiegeln.
So gibt es zum Beispiel Objekte für eine Excel-Datei, ein Sheet in einer Datei und eine Zelle eines Sheets.
Eine Datei kann über eine Funktion der Bibliothek erstellt werden, ein Sheet kann über das Datei-Objekt erstellt werden
und ein Zell-Objekt über das Sheet-Objekt.

Für den Excel-Export des Paper-Trackers wird zunächst eine neue Datei erstellt.
Diese ist nur im Hauptspeicher vorhanden und wird nicht auf die Festplatte geschrieben.
Weiter wird für jedes Workflow Template ein Sheet erstellt.
In dieses Sheet werden als Tabelle alle Ausführungen dieses Templates mit Informationen zu den Schritten geschrieben.
Dies geschieht schon während des Sammelns der Daten.
Ein Beispiel für ein solches Sheet ist in \autoref{fig:export-template} zu sehen.

\begin{figure}[htbp]
	
	\centering
	\caption{Template-Sheet eines Excel-Exports}
	\label{fig:export-template}
\end{figure}

Für die Übersicht der Revisionen wird zusätzlich ein separates Sheet erstellt.
In dieses werden nach dem Aufbereiten der Daten in einer Tabelle die verschiedenen ursprünglichen Revisionen
mit ihren folgenden Revisionen gelistet.
Hier werden auch die erfassten Metriken dargestellt.
Dies resultiert in dem in \autoref{fig:export-orig-revisions} dargestellten Sheet.

\begin{figure}[htbp]
	
	\centering
	\caption{Ursprüngliches Revisionen-Sheet eines Excel-Exports}
	\label{fig:export-orig-revisions}
\end{figure}

Die daraus entstandene Excel-Datei ist immernoch nur im Hauptspeicher vorhanden
und muss auch nicht auf die Festplatte geschrieben werden.
Das Objekt der Datei kann auf ein \enquote{io.Writer}-Interface,
das in der Standardbibliothek von Go enthalten ist, schreiben.
Dadurch kann das Objekt direkt in die Antwort der \gls{REST}-Schnittstelle die Datei schreiben.

\subsection{Tests}

Wie in allen Software-Projekten ist es wichtig, den Paper-Tracker zu testen.
Dabei spielt vor allem der Backend-Server ein große Rolle, da dieser die meiste Geschäftslogik implementiert.

Alle für den Server existierenden Tests sind automatisierte Tests, die einzelne Einheiten des Codes testen.
Vor allem werden die Manager getestet, da diese letztendlich die Geschäftslogik beinhalten.
Dafür werden verschiedene Bibliotheken verwendet.
Die \enquote{ginkgo}-Bibliothek stellt Funktionen zur Verfügung, um die Tests zu definieren
und Code vor/nach den Tests auszuführen.
Mit Hilfe von \enquote{gomega} können Ergebnisse der Tests mit zu erwartenden Ergebnissen verglichen werden.
Sie stellt neben den einfachen Vergleichen auch Vergleiche für Fehlertypen, komplexe verschachtelte Datenstrukturen,
Listen und mehr.

Damit die einzelnen Einheiten des Servers getrennt voneinander getestet werden können, wird zusätzlich die
\enquote{gomock} Bibliothek verwendet.
Diese ermöglicht es, Stellvertreterobjekte für in diesem Fall Manager und Repositories zu erstellen.
Die Stellvertreterobjekte können dann für jeden einzelnen Testfall mit zu erwarteten Parametern und einem Rückgabewert
konfiguriert werden.
Da \enquote{gomock} nur aus Interfaces Stellvertreterobjekte erstellen kann, müssen für alle Manager
und Repositories eigene Interfaces erstellt werden.
Deshalb gibt es, im Gegensatz zum Entwurf, für jeden Manager ein Interface und eine Implementierungsklasse.
Für die Tests wird dann die Instanz des Singletons auf ein Stellvertreterobjekt gesetzt.

Mit diesen Techniken wurden einige Tests für die Manager-, Modell- und Utilities-Klassen geschrieben.
Es sind somit ca. $20\%$ der Manager, ca. $27\%$ der Modelle und ca. $68\%$ der Utilities getestet.
Leider ist dies noch nicht ausreichend für eine gute Testabdeckung.
Vor allem, um komplexe Konstrukte wie den Fortschritt einer Workflow Ausführung zu testen, wäre um einiges mehr Zeit erforderlich
gewesen.

\section{App}

In diesem Kapitel wird die technische Umsetzung der App für Mobilgeräte beschrieben.

\subsection{Verwendete Technologien}

Zur Programmierung der App wurden die Programmiersprache Dart und das Framework Flutter verwendet.
Ein großer Vorteil dieser Kombination ist, dass Anwendungen sowohl für Android als auch für iOS
kompiliert werden können, ohne den Quellcode anpassen zu müssen. Auch eine Laufzeitumgebung für
Desktopcomputer unter Windows, macOS und GNU/Linux befindet sich aktuell im Teststadium, sodass die
Paper-Tracker App gegebenenfalls auch auf Arbeitsplatzrechnern verwendet werden kann.

Auch für das Erstellen der App wurden einige Bibliotheken verwendet, die die Entwicklung vereinfachen.
Vor allem werden zum Beispiel Bibliotheken verwendet, um die Kommunikation mit dem Backend-Server zu ermöglichen.
Die verwendeten Bibliotheken sind im Folgenden aufgelistet:
\begin{description}
	\item[http (https://pub.dev/packages/http)] \hfill \\
		\enquote{http} ist eine Bibliothek, die es ermöglicht, asynchron \gls{HTTP}-Anfragen durchzuführen. Die Bibliothek wird dafür verwendet, um mit dem Backend-Server zu kommunizieren.
	\item[json\_annotation (https://pub.dev/packages/json\_annotation)] \hfill \\
		Mit \enquote{json\_annotation} kann über Annotationen im Programmcode eine Serialisierung zu \gls{JSON} und Deserialisierung von \gls{JSON} für Datenklassen generiert werden.
	\item[shared\_preferences (https://pub.dev/packages/shared\_preferences)] \hfill \\
		Durch die \enquote{shared\_preferences} Bibliothek können einfache Konfigurationen als Schlüssel-Wert-Paare abgespeichert werden. Dies wird für die \gls{URL} des Backend-Servers verwendet.
	\item[material\_design\_icons (https://pub.dev/packages/material\_design\_icons\_flutter)] \hfill \\
		\enquote{material\_design\_icons} stellt zusätzliche Material\footnote{Eine Designsprache von
			Google, die in fast allen Google-Produkten eingesetzt wird und auf Minimalismus setzt.
			\cite{Google2020}}-Icons zur Verfügung. Dies ist notwendig, da die standardmäßig verfügbaren Icons in Flutter nicht ausreichend sind.
	\item[fluttertoast (https://pub.dev/packages/fluttertoast)] \hfill \\
		Mit \enquote{fluttertoast} können kleine Pop-ups dargestellt werden, die dem Nutzer der App einfach und schnell Feedback zu einer Aktion geben können.
	\item[url\_launcher (https://pub.dev/packages/url\_launcher)] \hfill \\
		Mit Hilfe von \enquote{url\_launcher} können \gls{URL}s im Browser des Smartphones geöffnet
		werden. Für den Paper-Tracker wird dies zum Download des Daten-Exports verwendet.
	\item[intl (https://pub.dev/packages/intl)] \hfill \\
		Die \enquote{intl}-Bibliothek wird für das Formatieren von Daten und Uhrzeiten verwendet. Zudem kann sie für die Übersetzung der App in andere Sprachen verwendet werden.
\end{description}

\subsection{Struktur der App}

Die Struktur der App teilt sich in fünf Teile auf.
Der erste Teil bildet die Hauptdatei, in der die App gestartet wird, sowie zusätzlich eine Konfigurations- und eine
Hilfsfunktions-Datei.
In der Hauptdatei wird neben dem Start der App auch das Design (hauptsächlich die zu verwendenden Farben) und die
Navigation aufgesetzt.
Die Navigation wird weiter unten detailiert erläutert.

Weiter sind im Unterordner \enquote{model} alle Modell-Klassen, die auch für den Server verwendet werden, vorhanden.
Für diese wird mit Hilfe der \enquote{json\_annotation} Bibliothek Code für die Serialisierung zu \gls{JSON} und die
Deserialisierung von \gls{JSON} generiert.

Um Daten dieser Modelle vom Server abzurufen, werden verschiedene Klienten-Klassen aus dem \enquote{client}-Ordner verwendet.
Es gibt einen grundlegenden Klienten, welcher eine Verfügbarkeitsabfrage und Anfragen an den Server zur Verfügung stellt.
Dieser verwendet die konfigurierte Server \gls{URL}.
Die Anfragen werden über die \enquote{http} Bibliothek ausgeführt.
Die weiteren Klienten (z.B. \enquote{RoomClient}) verwenden den grundlegenden Klienten und stellen Funktionen direkt im Bezug
auf die zugehörige Klasse des Klienten zur Verfügung.
So können über den \enquote{RoomClient} zum Beispiel alle Räume abgefragt werden.
Diese Klienten führen dann die Konvertierung von und zu \gls{JSON} durch.

Im \enquote{pages} Unterordner sind alle anzuzeigenden Seiten der App untergebracht.
Dies sind zum Beispiel die Hauptübersichtsseite oder die Detailseite für einen Raum.
Auf diesen Seiten werden sogenannte \enquote{Widgets} verwendet, aus denen letztendlich das Layout und der Inhalt einer
Seite zusammengesetzt werden.
Neben den durch die Standardbibliothek und weiteren Bibliotheken bereitgestellten Widgets werden auch selbst programmierte verwendet.
Diese befinden sich im \enquote{widgets} Unterordner.
Der Aufbau einer Seite und eines Widgets sind weiter unten näher erklärt.

\subsection{Routing}

Unter Routing versteht man die Navigation innerhalb der App auf verschiedene Routen und damit im Falle der Paper-Tracker
App auf verschiedene Seiten.
Für das Routing wird in der App die Standard-Klasse \enquote{MaterialApp} verwendet.
Dieser wird eine Zuordnung von einer Route zu einer Seite in Form einer Zeichenkette mitgegeben.

In der kompletten App kann dann über \enquote{Navigator.of(context)} auf die Navigation zugegriffen werden.
Der Kontext ist in jeder zur App zugehörigen Seite und Widget vorhanden.
Die Navigation bietet die folgenden wichtigen Funktionalitäten:
Mit \enquote{pushNamed} kann über die zuvor in der Zuordnung definierte Route auf die dazugehörige Seite navigiert werden.
Diesem Funktionsaufruf können auch Parameter mitgegeben werden, die von der geöffneten Seite verwendet werden können.
Über \enquote{pop} kann die zuletzt geöffnete Seite wieder geschlossen werden.
Dabei wird die zuvor geöffnete Seite wieder angezeigt oder bei der letzten Seite die App geschlossen.

Für die Paper-Tracker App gibt es für jede Seite eine eigene Route.
Diese Route ist in der Klasse der Seite statisch definiert.
Somit kann jederzeit in der App auf eine beliebige Seite navigiert werden.

Einige Beispiele für die Navigation innerhalb der App sind in \autoref{lst:app_navigation} aufgeführt.

\begin{lstlisting}[caption={Beispiele für die Navigation innerhalb der App},label={lst:app_navigation},tabsize=2]
// Navigiere zur ConfigPage
Navigator.of(context).pushNamed(ConfigPage.Route);

// Navigiere zur RoomPage mit der ID des Raumes als Parameter
Navigator.of(context).pushNamed(RoomPage.Route, arguments: room.id);

// Schließe die aktuelle Seite und kehre zur vorherigen zurück
Navigator.of(context).pop();
\end{lstlisting}

\subsection{Seiten}

Insgesamt beinhaltet die App elf verschiedene Seiten:
\begin{enumerate}
	\item InitPage
	\item ConfigPage
	\item ServerConfigPage
	\item MainPage
	\item WorkflowExecPage
	\item WorkflowTemplatePage
	\item RoomPage
	\item TrackerPage
	\item LearningPage
	\item StartExecPage
	\item TutorialPage
\end{enumerate}
Der Großteil der Seiten spiegelt Seiten aus dem Entwurf der App wieder.
Zwei dieser Seiten sind in \autoref{fig:app_pages} dargestellt.
Weitere Seiten, wie die \enquote{InitPage} oder \enquote{ConfigPage}, werden nur als Weiterleitung oder für nicht im
Entwurf beinhaltete Funktionen genutzt.

\begin{figure}[htbp]
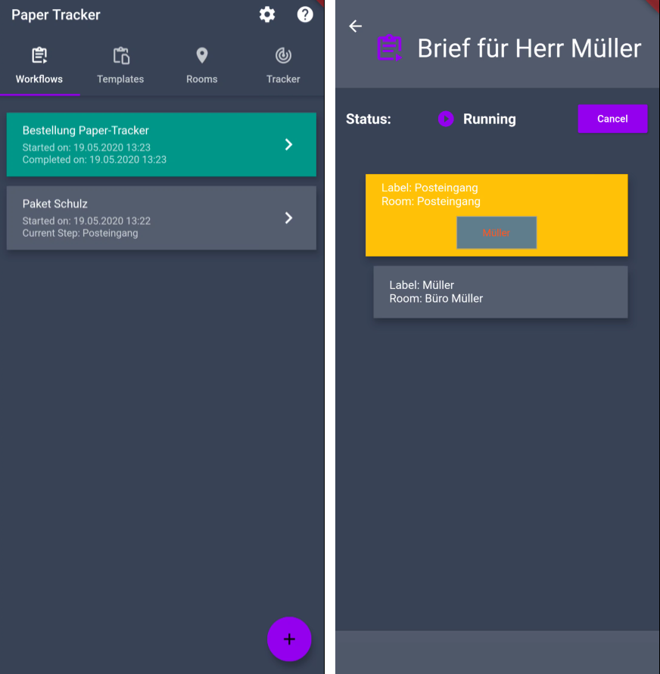
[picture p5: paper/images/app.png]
	
	\centering
	\caption{Umsetzung des App Entwurfs}
	\label{fig:app_pages}
\end{figure}

Eine Seite selbst ist, wie bereits erwähnt, aus verschiedenen Widgets zusammengesetzt.
Für alle Seiten der Paper-Tracker App wird dafür als Grundlage das \enquote{Scaffold}-Widget verwendet.
Dieses bietet eine \enquote{AppBar} als Titel für die Seite und als Container für z.b. eine Zurück-Schaltfläche.
Auch kann über das \enquote{Scaffold}-Widget ein \enquote{FloatingActionButton} für die Seite verwendet werden.
Dieser wird für die \enquote{WorkflowExecPage} zum Erstellen einer neuen Ausführung und für die \enquote{RoomPage}
zum Erstellen eines neuen Raums benötigt.
Der eigentliche Inhalt der Seite wird dem \enquote{Scaffold} als Parameter mitgegeben.
Ein \enquote{Scaffold} mit Titel und \enquote{FloatingActionButton} ist in \autoref{fig:app_scaffold} dargestellt.

\begin{figure}[htbp]
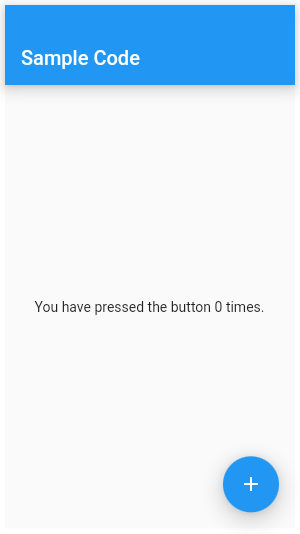
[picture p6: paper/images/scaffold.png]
	
	\centering
	\caption{Scaffold-Widget}
	\small Quelle: \url{https://api.flutter.dev/flutter/material/Scaffold-class.html}
	\label{fig:app_scaffold}
\end{figure}

Der eigentliche Inhalt der Seiten variiert stark und besteht gemischt aus Widgets der Standardbibliothek, weiteren Bibliotheken
und eigenen Widgets.
Die Widgets bauen letztendlich eine Baumstruktur auf.
Eine besonders wichtige Rolle spielt dabei unter anderem das \enquote{FutureBuilder} Widget.

Der \enquote{FutureBuilder} erlaubt einer Seite asynchron auf ein Ergebnis eines \enquote{Future}\footnote{Ein Future repräsentiert in Dart das Ergebnis
einer asynchronen Ausführung. Dabei kann ein Future entweder das Ergebnis selbst oder im Fehlerfall einen Fehler zurückgeben. \cite{dart2020}}
 zu warten.
Futures werden bei allen Anfragen über die Klienten an den Server verwendet, da die Ergebnisse der Netzwerkanfragen asynchron sind.
Welche Widgets letztendlich durch den \enquote{FutureBuilder} angezeigt werden, entscheidet sich in einer Funktion,
die dem Widget mitgegeben wird.
In dieser Funktion kann je nachdem, ob ein Ergebnis vorhanden ist und ob das Ergebnis die erwarteten Daten oder
ein Fehler ist, entsprechend weitere Widgets gebaut werden.
Ein Beispiel ist in \autoref{lst:app_futurebuilder} aufgelistet.

\begin{lstlisting}[caption={Beispiel für die Verwendung des \enquote{FutureBuilder}},label={lst:app_futurebuilder},tabsize=2]
@override
Widget build(BuildContext context) {
	return FutureBuilder(
		future: RoomClient.getAllRooms(),
		builder: (context, snapshot) {
			if (snapshot.hasData) {
        // Zeige eine Raumliste bei erfolgreichem Abfragen der Daten an
				return RoomList(snapshot.data);
			} else if (snapshot.hasError) {
        // Zeige einen Fehler bei Auftreten an
        return Center(child: Text("${snapshot.error}"));
      }
      // Falls es noch kein Ergebnis gibt, zeige einen Ladekreis an
			return CircularProgressIndicator();
		},
	);
}
\end{lstlisting}

\FloatBarrier
\subsection{Widgets}

Wie bereits erwähnt, wurden einige Widgets, die auf den Seiten der App verwendet werden, selbst programmiert.
Dies hilft dabei duplizierte Konstellationen von Widgets auf verschiedenen Seiten zu verringern, indem man diese
verallgemeinert und als eigenes Widget zur Verfügung stellt.
Auch können in diesen Widgets bestimmte Design-Formatierungen gemacht werden, die dann an dieser Stelle zentral verwaltet
werden können.
Allgemein können die eigenen Widgets in drei Kategorien aufgeteilt werden:
Dialoge, Listen und allgemeine Widgets.

Dialoge beinhalten teilweise generalisierte und teilweise spezialisierte Dialoge, die von den Seiten aus aufgerufen werden können.
Ein Beispiel für einen generalisierten Dialog ist ein einfacher \enquote{Bestätigen} Dialog.
Ein spezialisierter Dialog ist der Dialog für das Eingeben der Parameter für einen neuen Raum.
Diese sind in der \autoref{fig:app_dialog} dargestellt.
Inhaltlich unterscheiden sich die Dialog-Widgets nicht von anderen Widgets.
Sie verwenden auch andere Widgets und passen diese je nach Logik des Dialogs gegebenenfalls etwas an oder stellen
Eingabefelder zur Verfügung.
Lediglich das Design der Dialog-Widgets ist darauf angepasst, in einem Dialogfenster angezeigt zu werden.

\begin{figure}[htbp]
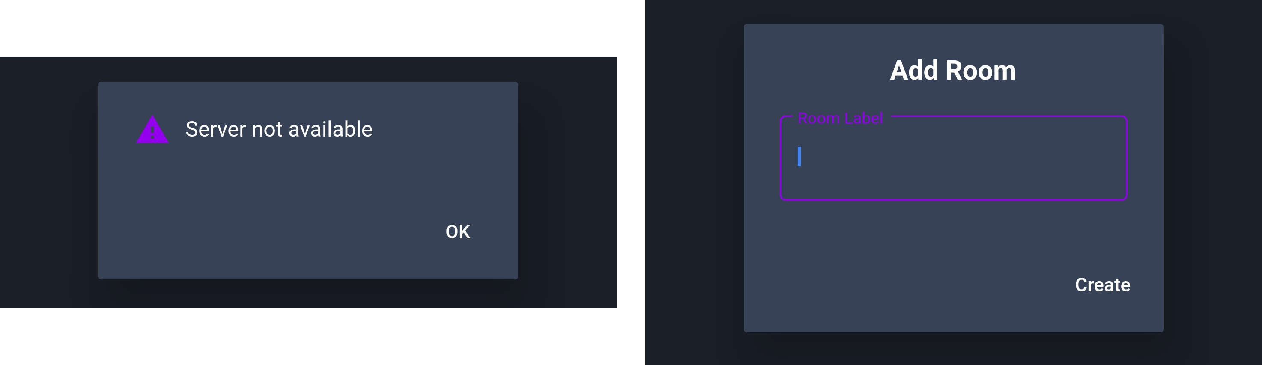
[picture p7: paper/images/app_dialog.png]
	
	\centering
	\caption{Dialog Widgets}
	\label{fig:app_dialog}
\end{figure}

Unter den Listen-Widgets sind zum einen allgemeine Listen, die dem Design aus dem Entwurf der App entsprechen, und zum
anderen Listen für spezifische Modell-Klassen.
Diese Listen basieren auf den allgemeinen Listen.
So gibt es zum Beispiel Listen für Räume, Tracker oder auch die Schritte eines Workflows.
Die verschiedenen Listen sind in \autoref{fig:app_lists} zu sehen.

\begin{figure}[htbp]
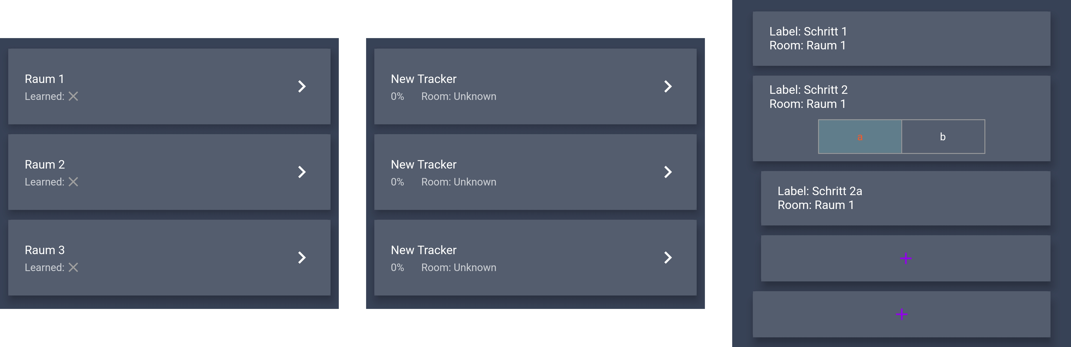
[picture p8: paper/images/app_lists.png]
	
	\centering
	\caption{Listen Widgets}
	\label{fig:app_lists}
\end{figure}

Unter den allgemeinen Widgets gibt es zum Beispiel Auswahllisten oder ein Countdown.

Alle Widgets können Parameter entgegennehmen, die zur Übergabe von Einstellungen für dieses Widget oder als Rückgabe
von Informationen dienen können.
Als Rückgabe werden meistens entweder sogenannte \enquote{Callback}-Funktionen oder \enquote{Controller} verwendet.
Callback-Funktionen sind Funktionen von zum Beispiel der Seite, die das Widget verwendet, die dem Widget als Parameter
mitgegeben werden.
Möchte das Widget Informationen zurückgeben, wird der entsprechende Callback aufgerufen und als Parameter die eigentliche
Funktion mitgegeben.
Verwendet das Widget einen Controller wird dem Widget ein Objekt mitgegeben, welches die zu verschickenden
Informationen speichern kann.
Da dem Widget selbst nur eine Referenz des Objektes mitgegeben wird, kann das Widget neue Informationen einfach in dieses
Controller-Objekt schreiben.

\section{Hardware-Gehäuse}

Neben der Hardware des spezifischen Trackers und der Software wurde auch ein Hardware-Gehäuse entwickelt.
Dieses Gehäuse soll den Tracker mit der Batterie beinhalten und eine Möglichkeit bieten, dieses an einem Stapel Papier zu befestigen.
Die Herstellung des Gehäuses soll in einem 3D-Drucker erfolgen.
Dazu muss das Gehäuse digital modelliert werden.

Bevor die Modelle selbst erstellt werden können, muss ein grobes Layout vorliegen.
Für den Paper-Tracker wurden zwei verschiedene Layouts in Betracht gezogen.
Diese werden in den folgenden Sektionen genauer erläutert und die aus den Layouts entstandenen Modelle gezeigt.

\subsection{Layout Controller auf der Batterie}
Das erste Layout ist in \autoref{fig:case-lay-on} abgebildet.
Bei diesem Layout befindet sich der Mikrocontroller auf der Batterie.

\begin{figure}[htbp]
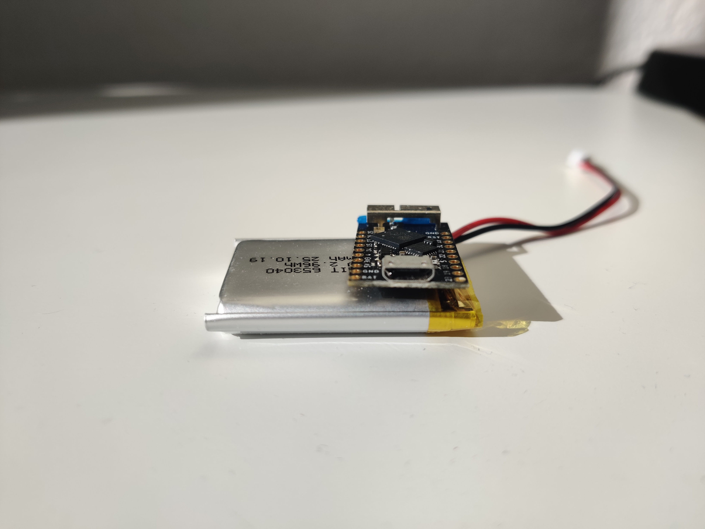
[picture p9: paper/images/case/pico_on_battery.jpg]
	
	\centering
	\caption{Gehäuse-Layout mit Mikrocontroller auf der Batterie}
	\label{fig:case-lay-on}
\end{figure}

Dies ergibt den Vorteil, dass die Grundfläche des Trackers mit ca. 45x35mm sehr gering gehalten wird.
Daraus ergibt sich dementsprechend der Nachteil, dass mit ca. 15mm die Konstruktion relativ hoch wird.

Das aus dem Layout entstandene Modell besteht aus zwei verschiedenen Teilen: Dem Körper des Gehäuses und dem Deckel.

Der Körper ist in \autoref{fig:case-high-body} dargestellt.
Er bietet eine Art Schublade, in welche die Batterie hineinpasst.
Oberhalb der Schublade wird der Mikrocontroller durch Wände am Platz gehalten.
An der Seite gibt es eine Aussparung, um den \gls{USB}-Port zum Laden benutzen zu können.

Geschlossen wird der Körper mit dem Deckel.
Dies ist in \autoref{fig:case-high} dargestellt.
Die beiden Teile sollen nur über das Zusammenstecken miteinander verbunden werden.
Am Deckel ist auch der Mechanismus zum Anklemmen des Gehäuses an Papier angebracht.
Er besteht aus einem Steg, der schräg zum Gehäusekörper zeigt.
Zudem sind Noppen angebracht, die die Grifffestigkeit erhöhen sollen.

\begin{figure}[htbp]
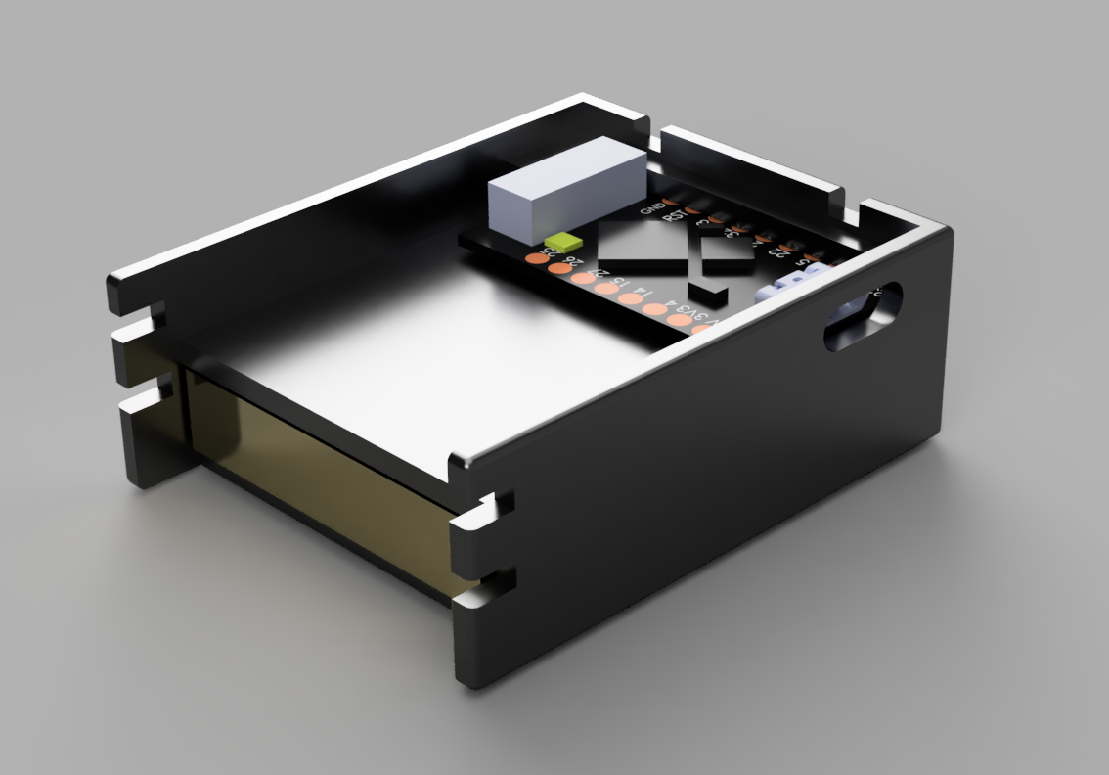
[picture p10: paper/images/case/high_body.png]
	
	\centering
	\caption{Körper des Gehäuse-Modells mit Controller auf der Batterie}
	\label{fig:case-high-body}
\end{figure}

\begin{figure}[htbp]
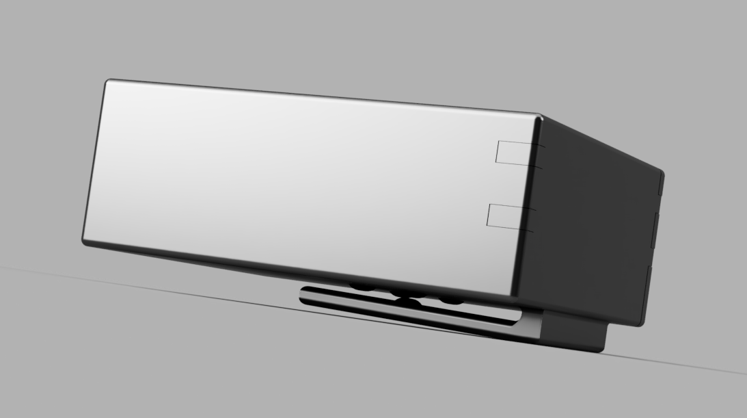
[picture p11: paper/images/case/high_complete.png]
	
	\centering
	\caption{Gehäuse-Modells mit Controller auf der Batterie}
	\label{fig:case-high}
\end{figure}

\FloatBarrier

\subsection{Layout Controller neben der Batterie}
Das zweite Layout ist in \autoref{fig:case-lay-beside} abgebildet.
Der Unterschied zum ersten Layout ist, dass der Mikrocontroller neben der Batterie platziert wird.

\begin{figure}[htbp]
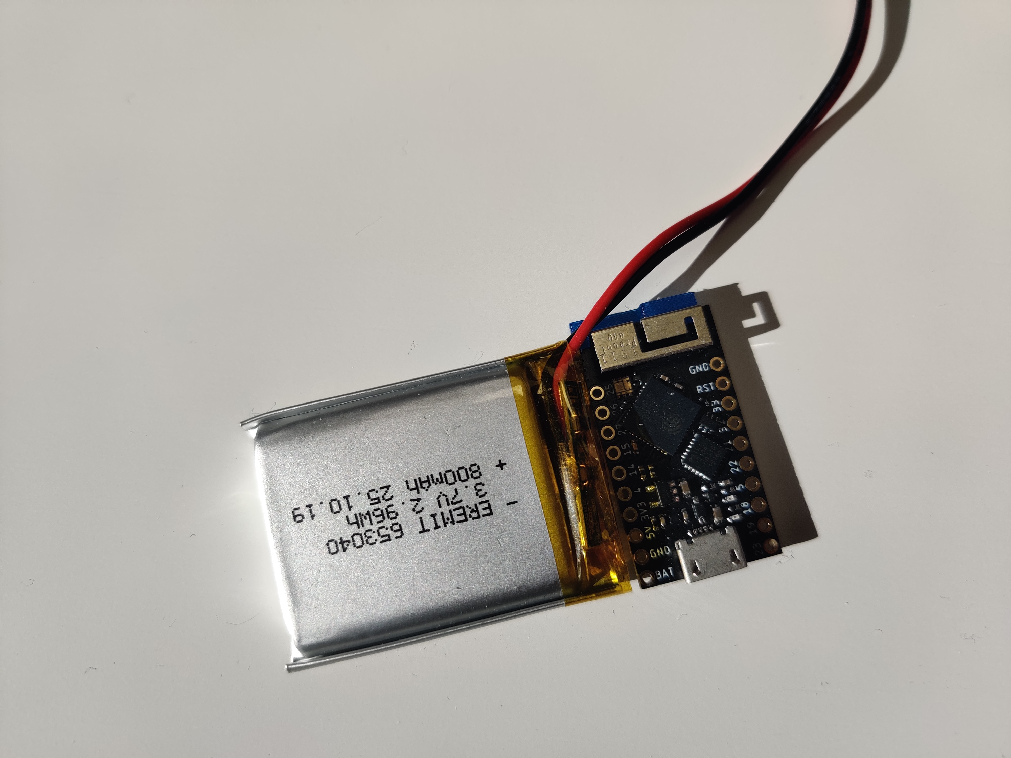
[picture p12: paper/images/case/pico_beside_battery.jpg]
	
	\centering
	\caption{Gehäuse-Layout mit Mikrocontroller neben der Batterie}
	\label{fig:case-lay-beside}
\end{figure}

Dies resultiert in einer erhöhten Grundfläche zum ersten Layout von 70x35mm, aber in einer Reduktion der Höhe auf nur 12mm.

Das Modell nach diesem Layout ist in drei verschiedene Teile aufgeteilt.
Es gibt, wie beim ersten Layout, auch einen Körper und einen Deckel.
Zusätzlich gibt es jedoch noch den Clip zum Befestigen an Papier.
Dieser ist demnach nicht mehr im Deckel mit enthalten.

Der Körper ist in \autoref{fig:case-low-body} dargestellt.
Er bietet Platz für die Batterie und den Mikrocontroller nebeneinander.
Für den \gls{USB}-Port ist ebenfalls in der Außenwand eine Aussparung vorhanden.
Kleine Erhebungen halten die Teile am Platz und verhindern ein Umherschieben.
In diesen Erhebungen sind auch Löcher für Schrauben inkludiert und auf der Unterseite Platz für eine Mutter.
Der größere Einschnitt in der Unterseite ist für den Clip bestimmt.

\begin{figure}[htbp]
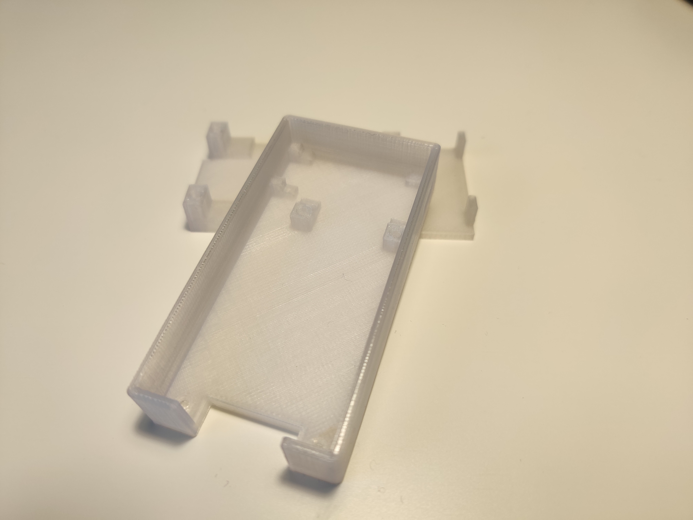
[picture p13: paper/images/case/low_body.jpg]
	
	\centering
	\caption{Körper des s mit Controller neben der Batterie}
	\label{fig:case-low-body}
\end{figure}

Der Deckel des Modells ist ähnlich dem Körper, besitzt aber keine Außenwände.
Er ist in \autoref{fig:case-low-lid} abgebildet.
Die kleinen Erhebungen des Deckels fixieren die Teile innerhalb des Gehäuses auf der vertikalen Achse.
Statt Platz für eine Mutter auf der Außenseite der Erhebungen mit Schraubenlöchern, ist eine Einsenkung für den Schraubkopf vorgesehen.

\begin{figure}[htbp]
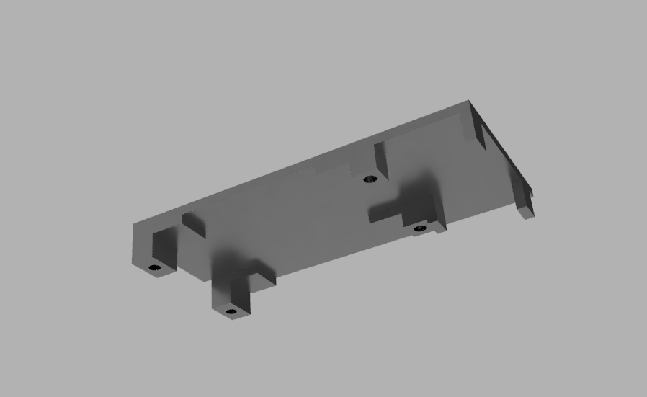
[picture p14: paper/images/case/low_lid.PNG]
	
	\centering
	\caption{Deckel des Gehäuse-Modells mit Controller neben der Batterie}
	\label{fig:case-low-lid}
\end{figure}

Angebracht ist der Clip an dem Einschnitt im Körper und fixiert durch die zwei danebenliegenden Schraubenlöcher.
Die Schraube wird dabei zwischen den Erhebungen des Körpers und des Deckels, sowie durch die in
\autoref{fig:case-low-clip} dargestellten Flügel des Clips geführt.
Für die Fixierung an einem Papierstapel wurde die gleiche Technik wie für das erste Layout verwendet.
Um den 3D-Druck zu simplifizieren wurden bei diesem Entwurf jedoch keine Noppen an den Clip und an
den Körper des Gehäuses angebracht. Diese werden nach dem Druck aufgeklebt.

\begin{figure}[htbp]
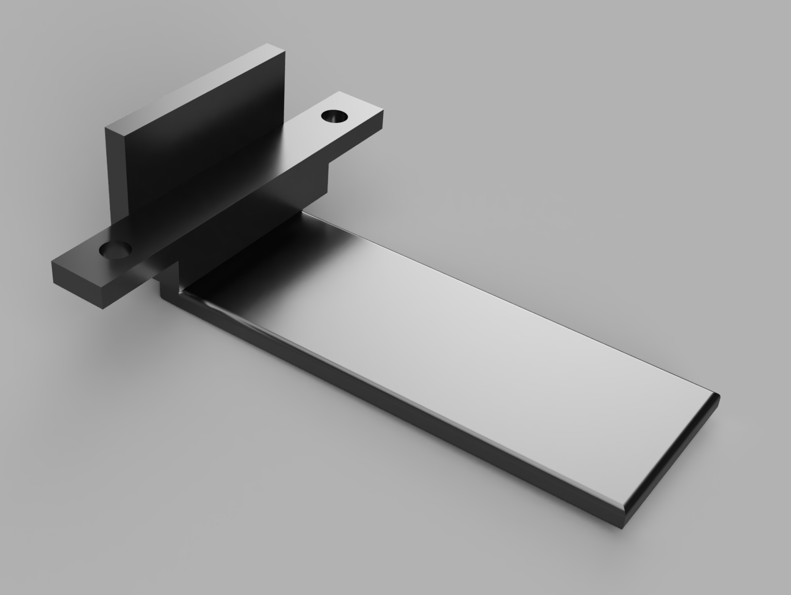
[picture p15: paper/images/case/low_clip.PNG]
	
	\centering
	\caption{Clip des Gehäuse-Modells mit Controller neben der Batterie}
	\label{fig:case-low-clip}
\end{figure}

\section{Bestehende Herausforderungen}

Es konnte zwar eine funktionierende und fast vollständige Lösung implementiert werden, die jedoch noch ein paar
Herausforderungen beinhaltet.
Dies sind mehrere Anpassungen oder Fehler, die aufgrund der begrenzten Projektzeit nicht angegangen werden konnten.

\subsection{\glsentrylong{UI}-Details in der App} \label{sec:impl-challenges-ui}

Innerhalb der App für den Paper-Tracker gibt es eine fehlende Funktion, die noch nicht implementiert wurde.
Dies ist die Unterstützung für mehrere Räume pro Schritt in einem Workflow Template.
Aktuell kann nur ein Raum ausgewählt werden, der immer in einer eigenen Liste an erster Stelle an den Server geschickt wird.
Konkret müssten auf der \enquote{WorkflowTemplatePage} und den dazugehörigen Widgets alle Auswahllisten für einen Raum durch
eine Mehrfachauswahl ersetzt werden.
Weiter müsste das Widget für die Darstellung von Steps eines Templates so angepasst werden, dass es
mehrere Räume anzeigen kann.

Zusätzlich zu dieser funktionalen Änderung, sollten einige nichtfunktionale Änderungen durchgeführt werden.
Zum einen muss das Farbschema der App überarbeitet werden.
Der Kontrast zwischen dem Violett und verschiedenen Hintergrundfarben liegt lediglich zwischen $1.21:1 - 1.68:1$.
Empfohlen wird laut dem Kriterium 1.4.3 in \cite{W3C2018} ein Kontrastwert von mindestens $4.5:1$.
Auch weitere verwendete Farben sind schwer erkennbar und können durch bessere ersetzt werden.

Die Mehrfachauswahl der für das Einlernen eines Raumes verwendeten \gls{SSID}s besitzt einen kleinen Fehler, der jedoch
für den Benutzer sehr verwirrend sein kann.
Es ist möglich die Auswahlbox eines Eintrages der Liste durch Drücken auf den gesamten Eintrag zu setzen, jedoch nicht
bei einem Druck auf die Auswahlbox selbst.
Dies kann dem Nutzer suggerieren, dass er keine Auswahl treffen kann, da meistens versucht wird, mit der Auswahlbox selbst
zu interagieren.

Zum Schluss exisitiert noch eine Inkonsistenz in der Nutzung von Textfeldern innerhalb der App.
Bei einigen Textfeldern, zum Beispiel in dem Dialog zum Erstellen eines Raumes, ist der Text der letzten Eingabe vorausgefüllt.
In anderen Textfeldern ist dies nicht der Fall und das Feld ist bei jedem Öffnen des Dialogs leer.
Hier muss sich auf ein konsistentes Verhalten geeinigt werden und dieses konsequent in der App umgesetzt werden.

\subsection{Messung des Batteriestandes}

Wie in \autoref{sec:hardware-used-technologies} beschrieben, stellt die TinyPICO-Plattform eine
Bibliothek bereit, mit der die Spannung des \gls{Akku}s abgefragt werden kann und somit der aktuelle
Ladestand berechnet werden kann. Diese Information ist wertvoll, um zu verhindern, dass ein Workflow
nicht richtig getracked wird, weil der \gls{Akku} eines Trackers leer wird. Daher wird der
Ladestand, wie in \autoref{tab:detail-attributes} gezeigt, auch in der App dargestellt. Dies macht das
Überprüfen des Ladestandes sehr komfortabel.

Problematisch ist jedoch, dass die Spannung des \gls{Akku}s nur sehr grob gemessen wird, was dazu
führt, dass der Tracker bei zwei direkt hintereinander durchgeführten Abfragen des Ladestandes mit
Schwankungen bis zu $5\%$ antwortet. Dieses Hindernis lässt sich durch weitere Hardware, welche
die Spannung misst, überwinden. Dies würde den Tracker weiter vergrößern, weswegen diese Option
nicht in Frage kommt. Eine weitere mögliche Lösung könnte eine Filterung nach mehreren Messungen
sein. Diese könnte auf Seiten des Trackers oder im Server implementiert werden.

Auch der Ladestatus, also ob ein Tracker aktuell aufgeladen wird oder sich entlädt, wird von der
gelieferten Bibliothek nicht immer korrekt wiedergegeben. Dies kann dazu führen, dass ein sich
entladender Tracker in der App vorübergehend als ladend angezeigt wird. Auch für die Korrektur dieses
Fehlers wäre externe Hardware nötig. Anders als das vorherig beschriebene Problem kann hierfür kein
Filter genutzt werden, da auch mehrere hintereinander durchgeführte Abfragen des Status sehr häufig zum
gleichen Ergebnis führen, auch wenn dieses falsch ist.

\subsection{Weitere Verkleinerung des Trackers}

Es konnte mit dem ausgewählten Mikrocontroller und der Batterie schon ein kompakter Tracker erreicht werden.
Trotzdem wäre mit einer weiteren Optimierung durch zum Beispiel einem für das Projekt angepassten \gls{PCB}
oder einer kleineren Batterie in Kombination mit reduziertem Stromverbrauch ein noch kompakterer Tracker möglich.

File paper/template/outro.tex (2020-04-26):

% ---- Glossar
\cleardoublepage
\printglossary[title=Glossar, toctitle=Glossar]

% ---- Literaturverzeichnis
\cleardoublepage
\renewcommand*{\chapterpagestyle}{plain}
\pagestyle{plain}
\pagenumbering{Roman}                   % Römische Seitenzahlen
\setcounter{page}{\numexpr\value{savepage}+1}
\printbibliography

% ---- Anhang
\appendix
%\clearpage
%\pagenumbering{Roman}  % römische Seitenzahlen für Anhang

\newpage

\ifthenelse{\boolean{final}}
	{}
	{\listoftodos}

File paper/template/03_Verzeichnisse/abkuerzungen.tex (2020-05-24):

\setacronymstyle{long-short} % Bei der ersten Referenz sollte <Langform> (<Kurzform>) ausgegeben werden

\newacronym{IoT}{IoT}{Internet of Things}
\newacronym{WLAN}{WLAN}{Wireless Local Area Network}
\newacronym{AP}{AP}{Access Point}
\newacronym{API}{API}{Application Programming Interface}
\newacronym{Akku}{Akku}{Akkumulator}
\newacronym{CoAP}{CoAP}{Constrained Application Protocoll}
\newacronym{HTTP}{HTTP}{Hypertext Transfer Protocol}
\newacronym{MQTT}{MQTT}{Message Queuing Telemetry Transport}
\newacronym{AMQP}{AMQP}{Advanced Message Queuing Protocol}
\newacronym{DHBW}{DHBW}{Duale Hochschule Baden-Württemberg}
\newacronym{LED}{LED}{Light Emitting Diode}
\newacronym{USB}{USB}{Universal Serial Bus}
\newacronym{UART}{UART}{Universal Asynchronous Receiver Transmitter}
\newacronym{BSSID}{BSSID}{Basic Service Set Identifier}
\newacronym{CBOR}{CBOR}{Concise Binary Object Representation}
\newacronym{JSON}{JSON}{JavaScript Object Notation}
\newacronym{REST}{REST}{Representational State Transfer}
\newacronym{IEEE}{IEEE}{Institute of Electrical and Electronics Engineers}
\newacronym{BSS}{BSS}{Basic Service Set}
\newacronym{MAC}{MAC}{Media Access Control}
\newacronym{ESS}{ESS}{Extended Service Set}
\newacronym{LAN}{LAN}{Local Area Network}
\newacronym{SSID}{SSID}{Service Set Identifier}
\newacronym{RSSI}{RSSI}{Received Signal Strength Indication}
\newacronym{RCPI}{RPCI}{Received Channel Power Indicator}
\newacronym{ORM}{ORM}{Object-relational mapping}
\newacronym{BDD}{BDD}{Behavior-driven development}
\newacronym{URL}{URL}{Uniform Resource Locator}
\newacronym{UI}{UI}{User Interface}
\newacronym{GUI}{GUI}{Graphical User Interface}
\newacronym{IP}{IP}{Internet Protocol}
\newacronym{XLSX}{XLSX}{Microsoft Excel Open XML Spreadsheet}
\newacronym{UDP}{UDP}{User Datagram Protocol}
\newacronym{ID}{ID}{Identifier}
\newacronym{CSV}{CSV}{Comma Separated Values}
\newacronym{PCB}{PCB}{Printed Circuit Board}

\renewcommand*{\glspagelistwidth}{.3\textwidth}

\printglossary[type=acronym, title=Abkürzungsverzeichnis, toctitle=Abkürzungsverzeichnis, style=longragged3col]

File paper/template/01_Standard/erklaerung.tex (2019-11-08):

\chapter*{Eidesstattliche Erklärung}
Wir versichern hiermit, dass wir unsere \arbeit{} mit dem Thema:
\begin{quote}
	\textit{\thetitle}
\end{quote}
gemäß § 5 der \enquote{Studien- und Prüfungsordnung DHBW Technik} vom 29. September 2017 selbstständig verfasst und keine anderen als die angegebenen Quellen und Hilfsmittel benutzt habe. Die Arbeit wurde bisher keiner anderen Prüfungsbehörde vorgelegt und auch nicht veröffentlicht.

\vspace{0.25cm}

Wir versichern zudem, dass die eingereichte elektronische Fassung mit der gedruckten Fassung übereinstimmt.

\vspace{1cm}

\verfassungsort, den \today \\[0.5cm]
\ifthenelse{\boolean{e-Abgabe}}
	{\underline{Gez. \theauthor}}
	{\makebox[10cm]{\hrulefill}}\\
\theauthor

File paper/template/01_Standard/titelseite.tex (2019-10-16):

\singlespacing

\thispagestyle{empty}
\begin{titlepage}
	\newgeometry{left=2.5cm, right=2.5cm, top=1.5cm, bottom=1.5cm}

\begin{figure}           % Logo vom Ausbildungsbetrieb und der DHBW
	\begin{minipage}{0.49\textwidth}
	\end{minipage}
	\hfill
	\begin{minipage}{0.49\textwidth}
		\flushright
		 
	\end{minipage}
\end{figure} 
\vspace*{1.0cm}

\begin{center}
	\huge{\thetitle}\\[3cm]
	\Large{\textsc{\arbeit}}\\[1cm]
	\normalsize{des Studienganges \studiengang}\\[1ex]
	\normalsize{an der Dualen Hochschule Baden-Württemberg Karlsruhe}\\[3cm]
\end{center}

\begin{center}
\begin{minipage}{0.35\textwidth}
	\centering
	\Large{Max Heidinger}\\
	\normalsize{2361793}
\end{minipage}
\begin{minipage}{0.35\textwidth}
	\centering
	\Large{Pascal Riesinger}\\
	\normalsize{7586259}
\end{minipage}
\end{center}
\vspace*{3em}

\begin{center}
	\vfill
	\setlength\tabcolsep{3em}
	\begin{tabular}{ll}
		Abgabedatum                     & \abgabe \\[0.2cm]
		Bearbeitungszeitraum            & \bearbeitungszeitraum \\[0.2cm]
		Kurs            								& \kurs \\[0.2cm]
		Betreuer 											  & \betreuerDhbw \\[0.2cm]
	\end{tabular} 
\end{center}

\restoregeometry
\end{titlepage}

\newcounter{savepage}
\pagenumbering{Roman}                    % Römische Seitenzahlen
\onehalfspacing

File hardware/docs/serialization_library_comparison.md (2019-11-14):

# Serialization library comparison

The following object has been serialized 250 times for the tests:

```cpp
ScanResult res{ -count, "AA:BB:CC:DD:EE", "MyWifi"};
```

which translates to

```json
{
  "RSSI": <-count>,
  "BSSID": "AA:BB:CC:DD:EE",
  "SSID": "MyWifi"
}
```

| Library | Serialization time (ms) | Result size (bytes) |
| --- | --- | --- |
| ArduinoJson | 460 | 38 |
| libCBOR | 77 | 28 |

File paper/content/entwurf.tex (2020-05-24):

\chapter{Entwurf} \label{chap:entwurf}

\section{Systemarchitektur} \label{sec:systemarchitektur}

In Abbildung \ref{fig:architecture} ist eine grobe Übersicht über die verschiedenen Komponenten des Projektes gegeben.
Es besteht aus drei Komponenten:
\begin{itemize}
	\item Hardware-Tracker
	\item Backend-Anwendung
	\item App
\end{itemize}

Der Hardware-Tracker ist die physische Komponente, die direkt an ein zu trackendes Papier angeheftet wird.
Er wird regelmäßig Daten erfassen und diese zur Lokalisierung an die Backend-Anwendung senden.

Die Backend-Anwendung dient als zentrales Element der Architektur.
Sie bekommt Daten des Trackers zugeschickt, wertet diese aus und speichert sie.
Auch das Management der Räume und Workflows wird von der Anwendung übernommen.

Nutzer verwenden zur Kommunikation mit dem Backend eine Smartphone-App.
Sie kommuniziert ebenfalls mit der Backend-Anwendung und fragt von dieser Informationen an oder löst Aktionen aus.

Die Entwürfe der drei Komponenten werden in den nachfolgenden Abschnitten im Detail erläutert.

Zusätzlich zu den drei Hauptkomponenten soll es ein Tool geben, dass das Setup eines Hardware-Trackers erleichtert.
Dieses Tool, genannt \enquote{Flasher}, dient zur Konfiguration der Firmware und dem Programmieren der Firmware auf die Hardware.

\begin{figure}[h!tbp]
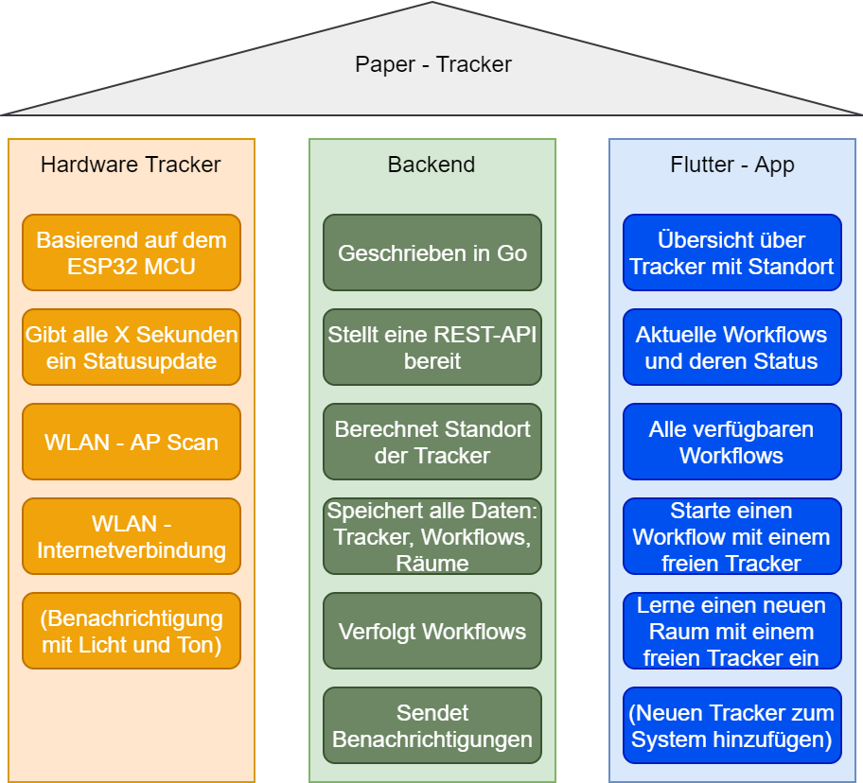
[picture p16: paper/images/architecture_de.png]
	
	\centering
	\caption{Architektur des Paper-Trackers}
	\label{fig:architecture}
\end{figure}

\section{Komponentenarchitektur} \label{sec:komponentenarchitektur}

In den folgenden Abschnitten wird detaillierter auf die einzelnen Komponenten des in
\autoref{sec:systemarchitektur} beschriebenen Systems eingegangen.
Dabei werden die Komponenten in derselben Reihenfolge beschrieben, in welcher die Daten im
Gesamtsystem fließen.

\subsection{Hardware-Tracker} \label{sec:tracking-hardware}

Zur Erfassung der Standortdaten der Dokumente werden, wie in \autoref{sec:soll-analyse}
beschrieben, Hardware-Tracker eingesetzt.
Diese verwenden jedoch keine absolute Positionierungstechnologie wie beispielsweise \gls{GPS}, da
das hierfür benötigte Satellitensignal in Gebäuden zu schwach ist und somit die Positionierung
fehlschlagen kann (vgl. \cite{Liu}).

Für die Lokalisierung von Geräten innerhalb eines Gebäudes gibt es daher mehrere Ansätze, wie in
\autoref{sec:stand-der-forschung} beschrieben wurde.
Da die Positionsdaten ohnehin zur Auswertung an das Backend übertragen werden müssen, wofür eine
\gls{WLAN}-Verbindung notwendig ist, wird diese Methode eingesetzt.
Die gesammelten Daten werden dann im Anschluss an das Backend übermittelt.

Als Metrik für das Tracking über \gls{WLAN} können die in \autoref{sec:grundlagen-wlan} erläuterten
\gls{RSSI} oder \gls{RCPI} verwendet werden. Da diese Werte jedoch nicht unbedingt proportional zum
Abstand zum \gls{AP} wachsen oder fallen, da Funksignale durch unterschiedliche Materialien
unterschiedlich gedämpft werden, können sie nicht als absolut angesehen und verwendet werden.
Wie auf dem Server das eigentliche Einlernen eines Raumes und die Lokalisierung eines Trackers funktioniert,
ist in \autoref{sec:server-tracking} erläutert.

Die Kommunikation zwischen dem Tracker und dem Server läuft über Kommandos, die der Tracker sich beim Server abholt.
Dies ist in einem Sequenzdiagramm in \autoref{fig:tracker_comm} dargestellt.
Sobald der Tracker nach einem vorherigen Kommando aufwacht oder er zum ersten Mal gestartet wird, verbindet er sich zuerst
mit dem konfigurierten \gls{WLAN} Netzwerk.
Nachdem der Tracker verbunden ist, liest er seine zugewiesene Tracker ID aus dem Speicher.
Ist noch keine Tracker ID gespeichert, fordert er beim Server eine neue ID an.
Mit dieser ID kann der Tracker sich ein Kommando beim Server abholen.
Es gibt drei verschiedene Typen an Kommandos:
\begin{description}
	\item[SendTrackingInformation] \hfill \\
		Informationen über vorhandene \gls{WLAN}-Netzwerke an den Server schicken
	\item[SendInformation] \hfill \\
		Aktuellen Batteriestatus an den Server schicken
	\item[Sleep] \hfill \\
		Keine Aktion ausführen
\end{description}
Welcher Typ Kommando geschickt wird, entscheidet der Server je nach Status des Trackers.
Das Kommando wird direkt ausgeführt und dabei gegebenenfalls angefallene Ergebnisse an den Server geschickt.
Als Beispiel für ein Kommando ist das \enquote{SendTrackingInformation} weiter unten im Sequenzdiagramm dargestellt.

Mit dem Kommando erhält der Tracker zusätzlich eine Zeit, für die er schlafen soll.
Ist diese Zeit über einem bestimmten Grenzwert (z.B. 10 Sekunden), geht der Tracker in den sogenannten \enquote{Deep Sleep},
in welchem er möglichst wenig Strom verbraucht.
Wird dieser Grenzwert bei nur kurzen Zeiten nicht überschritten, wartet der Tracker die Zeit lediglich ab.
Dies verhindert ein ständiges Neuaufbauen der Verbindung zum \gls{WLAN}, welches sowohl Zeit als auch Strom kostet.
Nachdem die Zeit entweder im \enquote{Deep Sleep} oder wartend verbracht wurde, geht der Prozess wieder von vorne los.

\begin{figure}[]
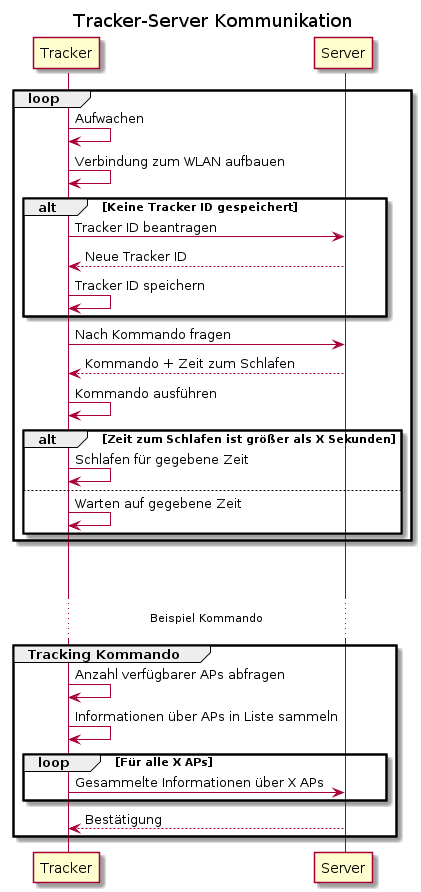
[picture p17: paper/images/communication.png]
	
	\centering
	\caption{Sequenzdiagramm Kommunikation zwischen Tracker und Server}
	\label{fig:tracker_comm}
\end{figure}

\FloatBarrier
\subsection{Backend-Anwendung} \label{sec:backend}

\subsubsection{UML Daten Modellierung}
Da die Backend-Anwendung die zentrale Komponente des Systems ist und auch die Daten verwaltet, werden für sie die Daten-Klassen modelliert.
Das resultierende UML-Diagramm ist in Abbildung \ref{fig:uml} abgebildet.

Die zentrale Klasse des Diagramms bildet die \enquote{Tracker}-Klasse.
Sie modelliert einen Hardware-Tracker.
Einige Attribute des Trackers sind eine ID, das Label, der Batteriestatus, eine Flag, ob ein niedriger Batteriestatus notifiziert wurde
und einige Zeitstempel.
Die Zeitstempel geben zum Beispiel an, wann zuletzt ein Kommando abgeholt wurde oder wann zuletzt der Batteriestatus aktualisiert wurde.
Mit Hilfe der letzten dem Tracker gesendeten Zeit zum Schlafen kann mit der Funktion \enquote{GetSecondsToNextPoll()} abgefragt werden,
wann sich der Tracker voraussichtlich das nächste Kommando abholt.
Neben den Attributen besitzt sie eine Referenz auf einen Status.
Dieser Status gibt an, zu was der Tracker zur Zeit verwendet wird und in welche anderen Zustände gewechselt werden kann.

Es gibt vier verschiedene Zustände, die in Integern kodiert sind:
\begin{description}
	\item[Idle = 1] \hfill \\
		Tracker ist frei verfügbar und kann in \enquote{Learning} oder \enquote{Tracking} übergehen.
	\item[Learning = 2] \hfill \\
		Tracker wird für das Lernen eines Raumes verwendet und kann bei erfolgreichem Abschluss in \enquote{LearningFinished} oder bei Abbruch in \enquote{Idle} übergehen.
	\item[LearningFinished = 3] \hfill \\
		Das Lernen eines Raumes mit diesem Tracker wurde beendet. Die Ergebnisse können berechnet und einem Raum zugewiesen werden. In Folge darauf geht der Tracker in den Zustand \enquote{Idle} über.
	\item[Tracking = 4] \hfill \\
		Der Tracker besitzt aktuell einen Workflow, den er trackt. Nach Abschluss dieses Workflows oder nach Abbruch geht der Tracker in den Status \enquote{Idle} über.
\end{description}

Weiter besitzt der Tracker eine Referenz auf eine aktive Workflow-Ausführung und den aktuellen Raum.
Beide Referenzen können nichtexistent sein, falls der Tracker keinen aktiven Workflow besitzt oder der Raum nicht bestimmbar ist.

Ein \enquote{Room} ist ein physikalischer Raum, der von einem Tracker erkannt werden soll.
Neben einem Identifizierer und einem \enquote{Label} (Name) für den Raum werden zusätzlich mehrere \enquote{BSSIDTrackingData} gespeichert.
Diese beinhalten für einen spezifischen \enquote{Access Point}/\gls{BSSID} einige Messdaten zu der gemessenen Signalstärke.
Über diese kann über eine Antwort des Trackers mit \enquote{ScanResults} die Position des Trackers bestimmt werden.

Damit der Tracker eine Antwort sendet, wird diese mit Hilfe eines Kommandos angefragt.
Diese Kommandos werden jeweils in einer Instanz der \enquote{Command}-Klasse abgebildet.
Die Kommandos besitzen einen spezifischen Typ der Enumeration \enquote{CommandType}, der die Aktion des Kommandos bestimmt.
Auch wird pro Kommando eine \enquote{SleepTimeSec} festgelegt, die bestimmt wie lange der Tracker sich nach der Aktion abschalten darf.

Spezielle Antworten der Tracker auf Kommandos und auch des Servers auf Anfragen der App sind in dem Unterpaket \enquote{communication} modelliert.
Dies ist zum Beispiel eine Fehler-Antwort und eine Basisklasse für Antworten des Trackers.
Diese \enquote{TrackerResponse}-Klasse besitzt auch ein Feld für den aktuellen Batteriestand des Trackers, um diesen überwachen zu können.

Unter den Klassen \enquote{WorkflowTemplate} und \enquote{WorkflowExec} sind die Workflows modelliert.
\enquote{WorkflowTemplate} stellt eine Blaupause dar, wie ein Workflow aussieht.
In diesem werden die einzelnen Schritte (\enquote{Steps}) des Workflows festgelegt.
Für einen \enquote{Step} werden ein Label und eine oder mehrere Referenzen auf dazugehörige Räume gespeichert.
Über die Klasse \enquote{NextStep} werden Referenzen auf nachfolgende Schritte modelliert.
Die \enquote{NextStep} Klasse besitzt ein Attribut \enquote{DecisionLabel}.
Ist dieses ein leerer String, so ist dieser verbundene Schritt ein linearer.
Mit einem nicht-leeren String gibt es mit diesem Schritt verschiedene Auswahlmöglichkeiten.
Durch das transitive Attribut \enquote{StepEditingLocked} der \enquote{WorkflowTemplate}-Klasse wird die Bearbeitung blockiert.
Dieses Attribut ist gesetzt, sobald es eine Ausführung des Templates gab.

Die \enquote{WorkflowExec}-Klasse stellt einen konkreten Workflow in der Ausführung dar.
Als Attribute besitzt diese Klasse ein Label, einen Status und Start-/Endzeit.
Der Status ist entweder \enquote{Running}, \enquote{Completed} oder \enquote{Canceled}.
Weiter besitzt die Klasse eine Referenz auf das Template, das ausgeführt wird, eine Menge an \enquote{ExecStepInfo} und an den aktuellen Schritt.
Die Klasse \enquote{ExecStepInfo} besitzt Informationen über einzelne Schritte des Workflows.
Dies sind zum einen die Start-/Endzeit des Schrittes sowie, ob der Schritt übersprungen wurde, und zum anderen die \enquote{Decision}-Information.
Der \enquote{Decision} String wird im Falle von mehreren Auswahlmöglichkeiten in einem Workflow dazu genutzt, in der Ausführung den richtigen Weg zu wählen.

\begin{figure}[h!tbp]
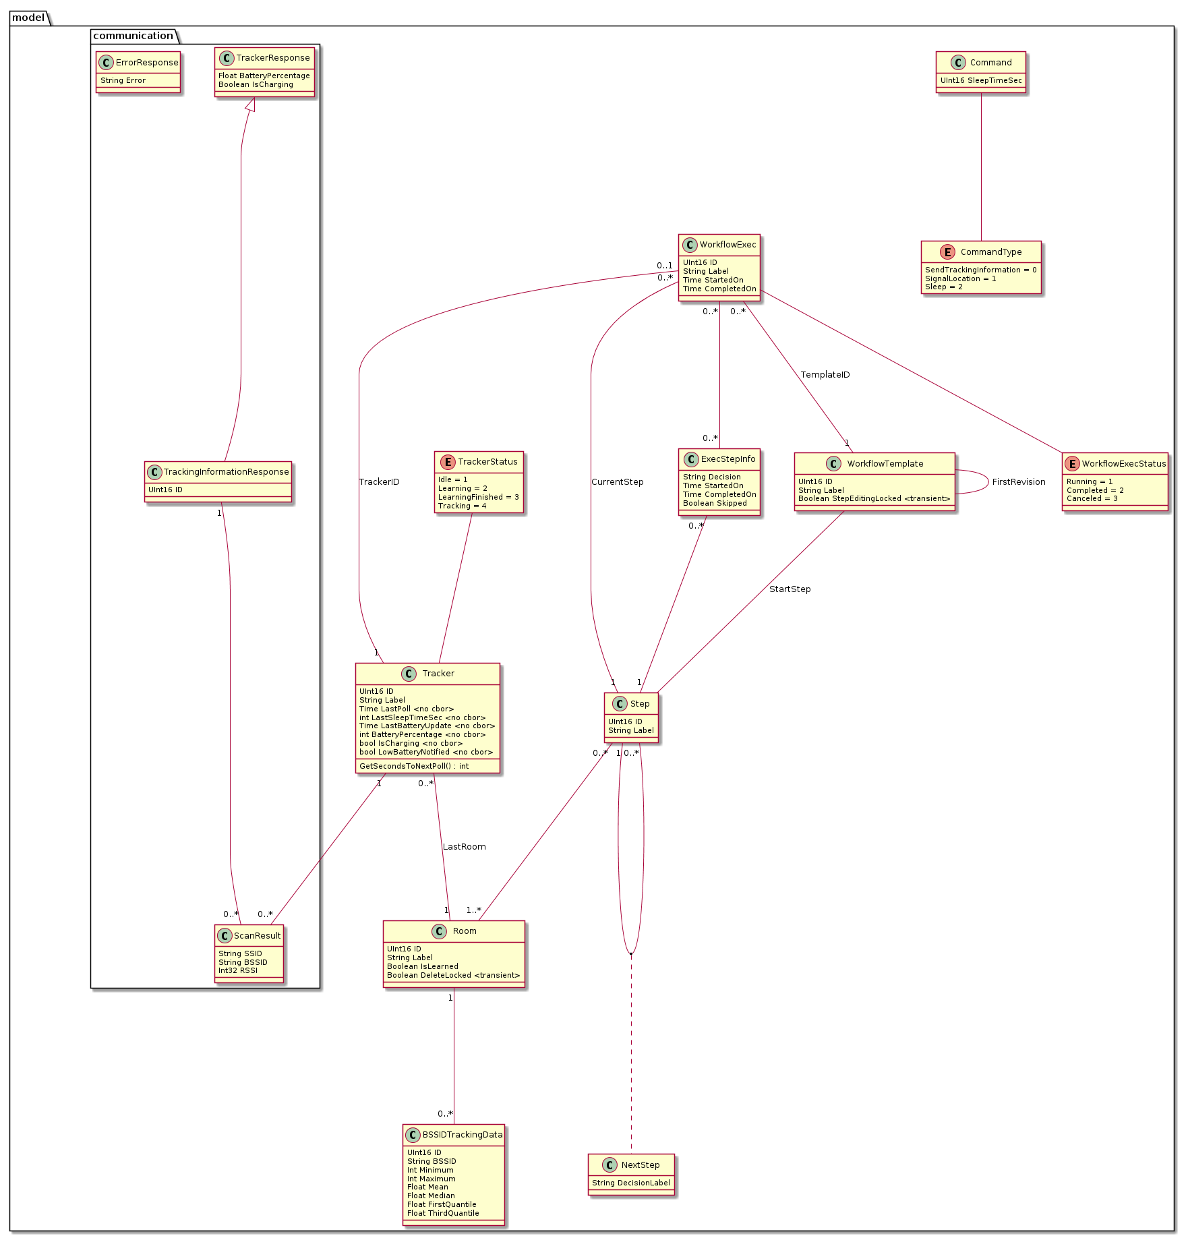
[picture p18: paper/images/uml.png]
	
	\centering
	\caption{UML-Diagramm für die Backend-Anwendung}
	\label{fig:uml}
\end{figure}

\FloatBarrier

\subsubsection{Schnittstellen}

Für die Backend-Anwendung sind zwei verschiedene Schnittstellen vorgesehen.
Eine Schnittstelle ist für den Tracker und eine für die App vorgesehen.
Die unterschiedlichen Schnittstellen sollen die aus der Analyse entwickelten Ansprüche entsprechend erfüllen.

\paragraph{Tracker-Schnittstelle} \label{par:tracker-schnittstelle}
Für die Schnittstelle des Trackers bedeutet dies, dass sie möglichst simpel und effizient sein muss.
Dies wird über ein entsprechendes Protokoll und ein Datenformat erreicht.
Das verwendete Protokoll ist das \gls{CoAP} und das Datenformat ist \gls{CBOR}.

Bei \gls{CoAP} handelt es sich um ein spezialisiertes Protokoll für die Verwendung in
\gls{IoT}-Hardware, welches dafür optimiert wurde möglichst wenig \gls{Overhead} zu haben.

Im \gls{IoT}-Bereich haben sich einige Protokolle durchsetzen können. Dazu zählen vor allem
\gls{HTTP}, \gls{MQTT}, \gls{AMQP} und \gls{CoAP}.
Da die Tracker batteriebetrieben sind, ist für diesen Anwendungsfall besonders die Performance des
eingesetzten Protokolles wichtig. Je weniger Overhead das Protokoll aufweist, desto weniger
Instruktionen müssen vom Prozessor des Trackers durchgeführt werden, was zu einer längeren Laufzeit
führt.
Werden die Protokolle anhand dieses Aspektes verglichen, erweist sich \gls{CoAP} als effizientestes
Protokoll. (vgl. \cite{Dizdarevic2019}, \cite{Naik2017})

\gls{CBOR} ist ein Datenformat, das auf kleine Code- und Nachrichtengrößen optimiert ist.
Demnach ist es auch für den \gls{IoT}-Bereich sehr gut geeignet.
Der Aufbau des Formats ist sehr gut mit \gls{JSON} vergleichbar, da es auch Schlüssel-Wert-Paare verwendet.
Der große Unterschied ist jedoch, dass \gls{CBOR} binär kodiert wird und \gls{JSON} in Text kodiert wird.
Dadurch ist \gls{CBOR} nicht menschenlesbar, aber sehr gut maschinenlesbar.
Bei einem Vergleich zwischen der \gls{CBOR} Bibliothek \enquote{libCBOR} und der \gls{JSON} Bibliothek \enquote{ArduinoJson}
konnte zudem festgestellt werden, dass bei gleicher Nachricht das \gls{CBOR} Format ca. 26.5\% kleinere Nachrichten
in 83.3\% der Zeit schnellerer serialisiert hat.

Die Tracker-Schnittstelle soll drei Endpunkte zur Verfügung stellen.
Diese sind in \autoref{tab:coap-api} aufgelistet.
Bis auf den Endpunkt zum Erstellen eines neuen Trackers, erhalten alle Endpunkte als Parameter die Tracker ID des Trackers, der die Anfrage stellt.
Der Endpunkt zum Speichern der Trackingergebnisse hat zudem als Parameter die Ergebnisse selbst.

\begin{table}[]
\begin{tabular}{l l l l}
\textbf{Verb} & \textbf{Pfad}     & \textbf{Aktion}                   & \textbf{Rückgabewert}    \\ \hline
POST          & /tracker/new      & Neuen Tracker erstellen           & Tracker ID \\ \hline
GET           & /tracker/poll     & Kommando für Tracker abfragen     & Tracker Kommando   \\ \hline
POST          & /tracker/tracking & Ergebnisse des Tracking speichern & -
\end{tabular}
\caption{\label{tab:coap-api}Verfügbare Endpunkte der Tracker-Schnittstelle}
\end{table}

\FloatBarrier
\paragraph{App-Schnittstelle} \label{par:app-schnittstelle}
Die Schnittstelle für die App hat keine besonderen Anforderungen und kann daher frei gewählt werden.
Aus diesem Grund werden Protokolle und Datenformate verwendet, die momentan dem aktuellen Stand der
Technik entsprechen.
Daraus ergibt sich der Vorteil, dass sie mit allen anderen gewählten Technologien sehr gut
kombinierbar sind und entsprechende Bibliotheken vorhanden sind.
Das verwendete Protokoll ist das \gls{HTTP}-Protokoll und das Datenformat ist \gls{JSON}.
Die Schnittstelle basiert auf dem \gls{REST} Paradigma (vgl. \cite{Fielding2000}).
Alle verfügbaren Endpunkte der App-Schnittstelle sind in \autoref{tab:http-api} dargestellt.

\begin{footnotesize}
\def\arraystretch{1.45}
\begin{landscape}
	\begin{longtable}{l|l|l|l|l}
		\caption{Liste aller Endpunkte der App-Schnittstelle \label{tab:http-api}} \\
\textbf{Verb} & \textbf{Pfad} & \textbf{Aktion} & \textbf{Parameter} & \textbf{Rückgabewert} \endfirsthead \hline
\textbf{Verb} & \textbf{Pfad} & \textbf{Aktion} & \textbf{Parameter} & \textbf{Rückgabewert} \endhead \hline
\multicolumn{5}{c}{\textit{Räume}} \\ \hline
\texttt{GET}    & \texttt{/room}     & Auflistung der Räume        & -    & Liste aller Räume                                                       \\ \hline
\texttt{POST}   & \texttt{/room}     & Erstellen eines neuen Raums & Raum & Erstellter Raum                                                         \\ \hline
\texttt{PUT}    & \texttt{/room/:id} & Raum aktualisieren          & Raum & Aktualisierter Raum                                                     \\ \hline
\texttt{DELETE} & \texttt{/room/:id} & Raum löschen                & -    & -                                                                       \\ \hline
\multicolumn{5}{c}{\textit{Tracker}} \\ \hline
\texttt{GET}    & \texttt{/tracker}                  & Auflistung der Tracker             & -                                                       & Liste aller Tracker                                                      \\ \hline
\texttt{PUT}    & \texttt{/tracker/:id}              & Tracker aktualisieren              & Tracker                                                 & Aktualisierter Tracker                                                  \\ \hline
\texttt{DELETE} & \texttt{/tracker/:id}              & Tracker löschen                    & -                                                       & -                                                                       \\ \hline
\texttt{GET}    & \texttt{/tracker/:id/next\_poll}   & Zeit zum nächsten Poll & -                                                       & Sekunden                                                                \\ \hline
\texttt{POST}   & \texttt{/tracker/:id/learn}        & Lernen mit Tracker starten         & -                                                       & Lernzeit                                                                \\ \hline
\texttt{GET}    & \texttt{/tracker/:id/learn}        & Lernstatus abfragen                & -                                                       & \begin{tabular}[c]{@{}l@{}}Abgeschlossen\\ Gefundene SSIDs\end{tabular} \\ \hline
\texttt{DELETE} & \texttt{/tracker/:id/learn}        & Lernen abbrechen                   & -                                                       & -                                                                       \\ \hline
\texttt{POST}   & \texttt{/tracker/:id/learn/finish} & Lernen abschließen                 & \begin{tabular}[c]{@{}l@{}}Raum ID\\ SSIDs\end{tabular} & \\ \hline
\multicolumn{5}{c}{\textit{Workflows}} \\ \hline
\texttt{GET}    & \texttt{/workflow/template}                   & Auflistung der Templates            & -                                                           & Liste aller Templates                                                   \\ \hline
\texttt{POST}   & \texttt{/workflow/template}                   & Template erstellen                  & Template                                                    & Erstelltes Template                                                     \\ \hline
\texttt{PUT}    & \texttt{/workflow/template/:id}               & Template aktualisieren              & Tempalte                                                    & Aktualisiertes Template                                                 \\ \hline
\texttt{DELETE} & \texttt{/workflow/template/:id}               & Template löschen                    & -                                                           & -                                                                       \\ \hline
\texttt{POST}   & \texttt{/workflow/template/:id/start}         & Start Schritt erstellen             & Step                                                        & Erstellter Step                                                         \\ \hline
\texttt{POST}   & \texttt{/workflow/template/:id/step}          & Schritt hinzufügen                  & \begin{tabular}[c]{@{}l@{}}Step\\ Vorgänger ID\end{tabular} & Erstellter Step                                                         \\ \hline
\texttt{GET}    & \texttt{/workflow/template/:id/step/:id}      & Schritt abfragen                    & -                                                           & Step                                                                    \\ \hline
\texttt{PUT}    & \texttt{/workflow/template/:id/step/:id}      & Schritt aktualisieren               & Step                                                        & Aktualisierter Step                                                     \\ \hline
\texttt{DELETE} & \texttt{/workflow/template/:id/step/:id}      & Schritt löschen                     & -                                                           & -                                                                       \\ \hline
\texttt{POST}   & \texttt{/workflow/template/:id/step/:id/move} & Schritt verschieben                 & Richtung                                                    & -                                                                       \\ \hline
\texttt{POST}   & \texttt{/workflow/template/revision}          & Template Revision erstellen         & Label                                                       & Erstellte Revision                                                      \\ \hline
\texttt{GET}    & \texttt{/workflow/exec}                       & Auflistung der Ausführungen         & -                                                           & Execution                                                               \\ \hline
\texttt{POST}   & \texttt{/workflow/exec}                       & Ausführung erstellen                & Execution                                                   & Erstellte Execution                                                      \\ \hline
\texttt{POST}   & \texttt{/workflow/exec/:id/progress/:id}      & Ausführung zu Schritt progressieren & -                                                           & -                                                                       \\ \hline
\texttt{POST}   & \texttt{/workflow/exec/:id/cancel}            & Ausführung abbrechen                & -                                                           & -                                                                       \\ \hline
\multicolumn{5}{c}{\textit{Sonstiges}}  \\ \hline
\texttt{GET} & \texttt{/export.xlsx} & Datenexport für Analyse & - & Excel-Datei            \\ \hline
\texttt{GET} & \texttt{/config} & Einstellungen abrufen & - & Konfigurierbare Einstellungen \\ \hline
\texttt{POST} & \texttt{/config} & Einstellungen setzen & Einstellungen & -
	\end{longtable}
\end{landscape}
\end{footnotesize}

\subsubsection{Software-Architektur}
\FloatBarrier
Die Architektur des Backend-Servers ist in folgendem Klassendiagramm \ref{fig:software-architecture} dargestellt.

Generell kann die Architektur in drei verschiedene Schichten aufgeteilt werden.
Die erste Schicht bildet das Paket \enquote{router}, die zweite Schicht das Paket \enquote{managers} und die dritte Schicht das Paket \enquote{repositories}.

Im \enquote{router} Paket befinden sich die Router für die zwei externen Schnittstellen des Servers.
Die \gls{HTTP} Schnittstelle für die App befindet sich in der \enquote{HttpRouter}-Klasse und die \gls{CoAP} Schnittstelle für den Tracker befindet sich in der \enquote{CoapRouter}-Klasse.
Beide Klassen besitzen eine Methode \enquote{Serve}.
Mit dieser Methode werden die Router letztendlich so gestartet, dass sie Verbindungen annehmen können.
Als Parameter bekommen sie die Adresse, auf der sie Verbindungen annehmen, und im Falle des \enquote{CoapRouter} auch das Transport-Protokoll.

Das \enquote{managers} Paket beinhaltet sechs verschiedene Manager, die die Businesslogik für verschiedene Teilbereiche
und damit Anforderungen des Servers beinhalten:
\begin{description}
	\item[TrackerManager] Anforderungen \ref{fa:tracking}, \ref{fa:neue-tracker}, \ref{fa:arbeitszeiten}, \ref{fa:wochenende}, \ref{fa:benachrichtigung} \hfill \\
		Verantwortlich für das Verwalten der Tracker. Entscheidet über die Kommandos für einen Tracker, wenn dieser ein Kommando abfragt.
	\item[RoomManager] Anforderung \ref{fa:raumplan} \hfill \\
		Verwaltet alle Operationen für Räume
	\item[LearningManager] Anforderung \ref{fa:tracking} \hfill \\
		Regelt das Einlernen von Scanergebnissen für einen Raum
	\item[WorkflowTemplateManager] Anforderungen \ref{fa:neue-workflows}, \ref{fa:mehrere-orte} \hfill \\
		Bietet Möglichkeiten zur Verwaltung der Templates
	\item[WorkflowExecManager] Anforderungen \ref{fa:tracking}, \ref{fa:optionale-schritte} \hfill \\
		Startet Templates als Ausführungen und führt Fortschritte eines Workflows durch
	\item[TrackingManager] Anforderung \ref{fa:tracking} \hfill \\
		Enthält Algorithmen für das eigentliche Tracking
	\item[ExportManager] Anforderung \ref{fa:export} \hfill \\
		Stellt den Excel-Export zur Verfügung
\end{description}
Alle Manager sind als Singleton implementiert, so dass sie sich auch untereinander problemlos aufrufen können.
Konfiguriert werden die Manager über die global verfügbare \enquote{Config} Klasse.

Die unterste Schicht bildet das \enquote{repositories} Paket.
Dieses enthält verschiedene Datenbank-Repositories, die die Datenbank und damit die Datenpersistenz des Servers abbilden.
Alle Methoden eines Repository bilden direkte Anfragen an die Datenbank.
Dabei ist ein Repository meist für eine Modellklasse verantwortlich.

Die main-Klasse ist für das Starten des Servers und das Erstellen der einzelnen Komponenten verantwortlich.
In dieser wird zum Beispiel auch die Konfiguration mit Hilfe der \enquote{Config}-Klasse eingelesen und initialisiert.

Die Config-Klasse ist global verfügbar und liest bei der Initialisierung aus einer Konfigurationsdatei
und über Kommandozeilenparameter verschiedene Einstellungen ein.
Die Einstellungen können dann über einzigartige Identifizierer abgefragt werden.
Auch stellt die Klasse Funktionen für das Abfragen und das Aktualisieren einer \enquote{EditableConfig} bereit.
Die \enquote{EditableConfig} ist eine reine Datenstruktur, welche vordefinierte Einstellungen beinhaltet, die während
der Laufzeit des Servers geändert werden dürfen.
Eine Aktualisierung der Einstellungen während der Laufzeit schreibt diese Änderungen auch in die Konfigurationsdatei.

Innerhalb dieser Config-Klasse sollen unter anderem auch die Einstellungen für die Anforderungen \ref{fa:arbeitszeiten}
und \ref{fa:wochenende} gespeichert werden.
Berücksichtigt werden diese Einstellungen im \enquote{TrackerManager}, wenn ein Tracker ein Kommando abfragt.

In der Utils-Klasse sind einige verschiedene Hilfsmittel untergebracht.
Dies sind zum einen das Versenden von E-Mails und zum anderen einige mathematische Hilfsfunktionen.

\begin{sidewaysfigure}
	% Ist nur .9\textheight breit, damit der Titel noch auf die seite passt
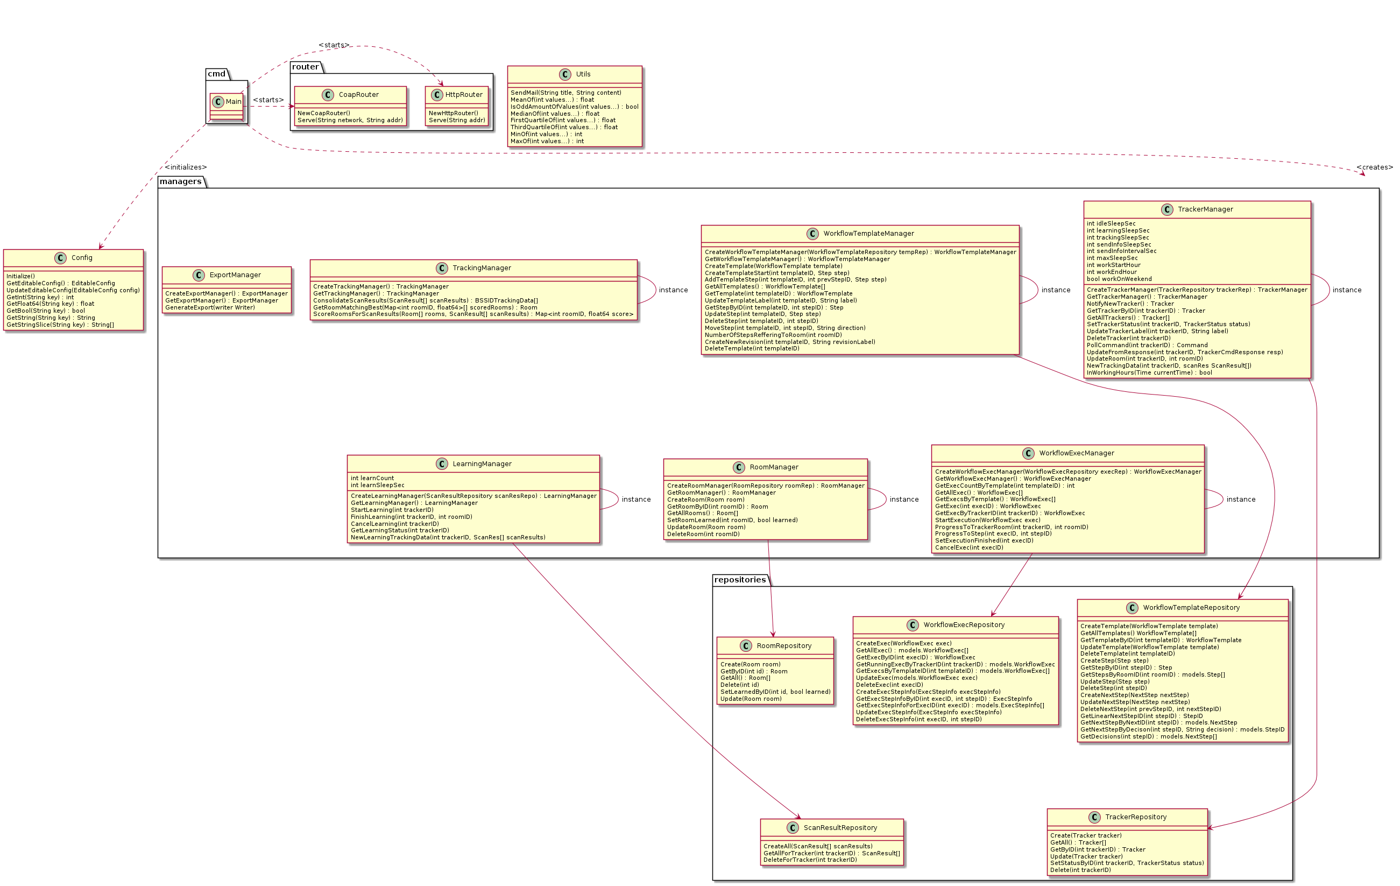
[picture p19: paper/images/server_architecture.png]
	
	\caption{Software-Architektur für die Backend-Anwendung}
	\label{fig:software-architecture}
\end{sidewaysfigure}

\FloatBarrier
\subsubsection{Tracker Lokalisierung} \label{sec:server-tracking}

Die raumgenaue Lokalisierung eines Trackers besteht aus zwei Teilen.
Der erste Teil ist das Einlernen eines Raumes mit Hilfe eines Trackers und der zweite das Zuordnen von Scanergebnissen
zu einem zuvor eingescannten Raum.

Beim Einlernen eines Raumes werden von einem Tracker, wie bei der eigentlichen Lokalisierung, Scanergebnisse angefordert.
Dies soll mehrfach über einen größeren Zeitraum geschehen.
Die genaue Anzahl an Wiederholungen und die Pause zwischen Scans soll konfigurierbar sein.
Nach den Scans liegen für alle verfügbaren \glspl{BSSID} ein oder mehrere \glspl{RSSI} (also Signalstärken) vor.
Weiter gehört jede \gls{BSSID} zu einer \gls{SSID}.

Diese Daten sollen im nächsten Schritt von dem Benutzer nach \glspl{SSID} gefiltert werden, die für die Lokalisierung
genutzt werden sollen.
Dadurch können zum Beispiel mobile \gls{WLAN}-Netzwerke von Smartphones, die nicht permanent vorhanden sind, herausgefiltert werden.
Dies verhindert ein Fehlschlagen einer Lokalisierung, wenn ein mobiles Netzwerk nicht verfügbar ist.

Nach der Filterung werden aus den mehreren \glspl{RSSI} pro \gls{BSSID} statistische Kenngrößen berechnet.
Diese werden im zweiten Teil für die Lokalisierung verwendet.
Berechnet werden, wie die Klasse \enquote{BSSIDTrackingData} zeigt:
\begin{itemize}
	\item Minimum
	\item Maximum
	\item Arithmetisches Mittel
	\item Median
	\item Erstes Quartil
	\item Drittes Quartil
\end{itemize}

Soll nun ein Tracker lokalisiert werden, werden von diesem wieder Scanergebnisse angefordert.
Dies liefert pro \gls{BSSID} einen \gls{RSSI}-Wert.
Um nun einen \enquote{besten} Raum aufgrund dieser Werte dem Tracker zuzuweisen, soll ein Scoring-System verwendet werden.
Dafür wird zuerst jedem Raum ein Score zugewiesen.
Die genaue Berechnung für diesen Wert soll während der Implementierung über verschiedene Tests herausgefunden werden.
Grob soll zum Beispiel für jeden \gls{RSSI}-Wert, der innerhalb des gespeicherten Minimum und Maximum dieser \gls{BSSID}
eines Raumes liegt, eine gewisse Punktzahl vergeben werden.
Auch ist eine Punktevergabe je nach Abstand vom Mittelwert und/oder Median denkbar.

Erhält ein Raum eine Punktzahl über einem bestimmten Schwellwert, ist dieser ein Kandidat für den Raum, in dem der Tracker
sich befindet.
Letztendlich wird der Raum gewählt, der über dem Schwellwert liegt und insgesamt die meisten Punkte erhalten hat.
Dieser Raum kann dann als aktueller Raum des Trackers eingetragen werden und für den Fortschritt einer Workflow-Ausführung
verwendet werden.
Der Schwellwert erzielt, dass einem Tracker, welcher sich in keinem eingelernten Raum befindet, nicht der nächstbeste
Raum zugewiesen wird.
In diesem Fall wird als Raum für den Tracker \enquote{Unbekannt} eingetragen und auch keine Workflow-Ausführung aktualisiert.

\subsubsection{Daten-Export}

Für einen Daten-Export muss zuerst ausgewählt werden, welche Daten exportiert werden sollen.
Da der Export des Paper-Trackers bei einer Optimierung der Workflows helfen soll, müssen hauptsächlich Daten der
Klassen \enquote{WorkflowTemplate}/\enquote{WorkflowExecution} und deren Umfeld exportiert werden.
Konkret wären dies die Templates und deren Ausführungen inklusive detailierter Infos der Schritte (\enquote{ExecStepInfo}).
Diese Informationen können helfen, langsame oder nicht benötigte Schritte eines Workflows zu identifizieren.

Weiter sollen auch Informationen zu den Revisionen eines Templates exportiert werden.
Anhand dieser Informationen kann verfolgt werden, ob Anpassungen eines Workflows einen Erfolg gebracht haben.
Dazu müssen zu den Revisionen einige Metriken erfasst werden.
Die zu erfassenden Metriken sind:
\begin{itemize}
	\item Anzahl der Ausführungen
	\item Prozentzahl der erfolgreich abgeschlossenen Ausführungen
	\item Durchschnittliche Dauer einer Ausführung
\end{itemize}

Mit der Auswahl der Daten kann auch das Format des Exports ausgewählt werden.
Alle zu exportierenden Daten können sehr gut in Tabellen exportiert werden.
Dies führt zu hauptsächlich zwei Exportformaten: \gls{CSV} und Excel.

\gls{CSV} ist ein weit verbreitetes und simples Format, da es hauptsächlich mit Kommas (',') und Zeilenumbrüchen arbeitet.
Dadurch ist es sehr einfach zu erstellen und einzulesen.
Die meisten Tools, die mit solchen Daten arbeiten, haben die Möglichkeit \gls{CSV}-Dateien einzulesen.
Ein großer Nachteil von \gls{CSV} ist jedoch, dass es nicht standardisiert ist und mehrere Arten
mit kleinen Unterschieden existieren (vgl. \cite{rfc4180}).
Im RFC-4180 werden lediglich scheinbar übereinstimmende Teile der verschiedenen Implementierungen dargestellt.
Nach diesen gibt es einen weiteren Nachteil: Pro \gls{CSV}-Datei kann nur eine Tabelle gespeichert werden.
Dies würde für den Export des Paper-Trackers bedeuten, dass entweder mehrere Dateien oder eine gebündelte Datei angeboten werden muss.

Excel oder genauer das von Excel verwendete \enquote{xlsx}-Format ist ein offenes und standardisiertes Format
für Kalkulationstabellen (vgl. \cite{iso29500}).
Da es ein offenes Format ist, kann es auch von anderen Programmen, wie Libre Office, geöffnet und bearbeitet werden.
Es muss nicht, wie bei \gls{CSV}, erst importiert werden.
Auch unterstützt es mehrere Tabellen in einer Datei, welches den Download des Exports vereinfacht.
Aus diesen Gründen wird Excel als Exportformat für den Paper-Tracker verwendet.

\FloatBarrier
\subsection{App für Mobilgeräte} \label{sec:app}

Die App für Mobilgeräte soll dem Endbenutzer die Möglichkeit geben, alles um den Paper-Tracker und die damit verbundenen Workflows einzusehen und zu bearbeiten.
Sie soll dafür die oben erwähnte \gls{REST}-Schnittstelle nutzen und deren Operationen dem Endbenutzer zur Verfügung stellen.

Die Oberfläche selbst soll möglichst intuitiv sein.
Um dies zu erreichen, wurden als Entwurf für die App einige Design-Prototypen erstellt, welche die grundlegenden Elemente der App darstellen.
Diese Prototypen wurden zum Teil per Hand auf Papier gezeichnet und zum Teil digital entworfen.

Alle Designs wurden größtenteils mit Designelementen entworfen, die im zu verwendenden \gls{UI}-Framework vorhanden sind.
Daher wurden auf Bausteine des
Flutter-Frameworks\footnote{https://flutter.dev/docs/development/ui/widgets} zurückgegriffen, welche
sich an die von Google entworfene Material-Designsprache halten (vgl. \cite{Google2020}).
Im Folgenden werden einige dieser Prototypen vorgestellt.

\FloatBarrier
\subsubsection{Hauptseite}

In \autoref{fig:ui-main-page} ist der Prototyp der Hauptseite der App zu sehen.
Die Hauptseite ist der zentrale Einstiegspunkt der App und bietet eine Übersicht über grundlegende
Informationen.

Allgemein ist die Hauptseite in einen Kopfbereich und einen Inhaltsbereich aufgeteilt.
Der Kopfbereich zeigt lediglich den Titel der App \enquote{Paper-Tracker} an und einen Button, mit dem das Tutorial aufgerufen werden kann.
Das Tutorial ist weiter in \autoref{sec:app-tutorial} beschrieben.
Im Inhaltsbereich gibt es weiter eine Aufteilung in verschiedene Tabs, die jeweils für eine Klasse im Datenmodell stehen.
Es soll einen Tab für Workflows in der Ausführung, Workflow-Templates, Räume und Tracker geben.
Jeder Tab und damit jede Klasse soll ein eindeutiges Icon zugewiesen bekommen, mit dem die Klassen auf verschiedenen Seiten der App wiedererkannt werden können.
Die Tabs sollen über ein Wischen nach links und rechts oder über ein Auswählen in der Tableiste gewechselt werden können.

In den Tabs wird jeweils eine Liste aller Objekte der entsprechenden Klasse mit den wichtigsten dazugehörigen Informationen angezeigt.
Dies ist zum Beispiel für einen Tracker der aktuelle Raum oder der Batteriestatus.

Über ein Pull-Down\footnote{Herunterziehen der Liste über den eigentlichen Inhalt hinaus.} der jeweiligen Liste kann diese aktualisiert werden.
Wenn der Nutzer einen Eintrag der Liste auswählt, soll sich eine Detailseite zu diesem Objekt öffnen.
Ein Design-Prototyp dazu ist in \autoref{sec:app-room} dargestellt.

Unten rechts in der Ecke ist ein \enquote{Floating Action Button} untergebracht.
Über diesen soll ein Dialog geöffnet werden, in dem ein neues Objekt der entsprechenden Klasse erzeugt werden kann.
Dazu ist weiter unten in \autoref{sec:app-dialog} auch ein Design-Prototyp beschrieben.

\begin{figure}[h!tbp]
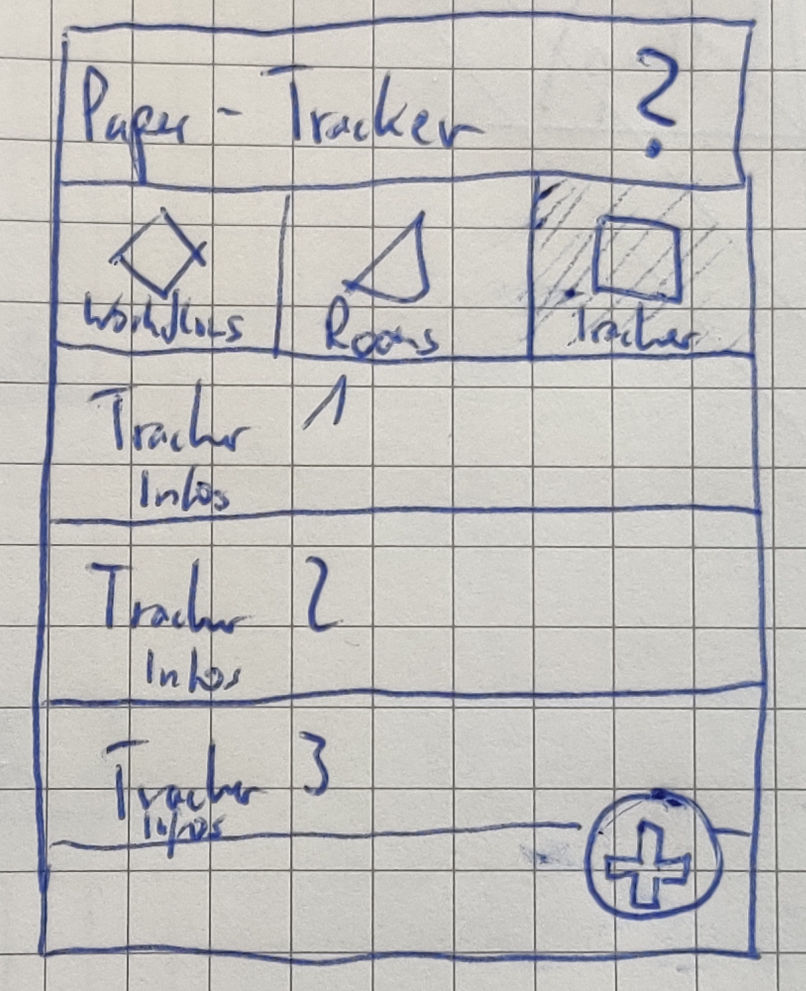
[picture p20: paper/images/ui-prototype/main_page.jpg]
	
	\centering
	\caption{Design-Prototyp der Hauptseite}
	\label{fig:ui-main-page}
\end{figure}

\FloatBarrier

\subsubsection{Darstellung von Workflows}

\autoref{fig:ui-workflow} zeigt den Prototyp für die Darstellung von Workflows.
Dies können sowohl Workflows in der Ausführung als auch Templates sein.

Die einzelnen Schritte eines Workflows sollen als Boxen in einer Liste dargestellt werden.
Der Nutzer muss in dieser Liste scrollen können, falls es in einem Workflow zu viele Einzelschritte
gibt, um diese auf einem Bildschirm anzeigen zu können.
Als letzte Box in der Liste wird ein Button angezeigt, mit dem der Nutzer einen neuen Schritt an die Liste anhängen kann.
Die Eingabe der Informationen des neuen Schrittes sollen in einem Dialog erfolgen.
Diese Box wird nur angezeigt, falls der anzuzeigende Workflow bearbeitbar ist.

In den Boxen zu den Schritten sollen einige Informationen angezeigt werden.
So werden beispielsweise der Name des Schrittes, der dem Schritt zugewiesene Raum und die
verfügbaren Optionen dargestellt.
Die Optionen sind jeweils einzelne Buttons.
Durch ein Auswählen eines Options-Buttons, werden die zu diesem Button gehörenden Schritte unter dem Schritt eingerückt angezeigt.
Diese Schritte werden wie oben beschrieben in einer identischen Liste angezeigt und unterstützen auch das Einfügen neuer Schritte.

\begin{figure}[h!tbp]
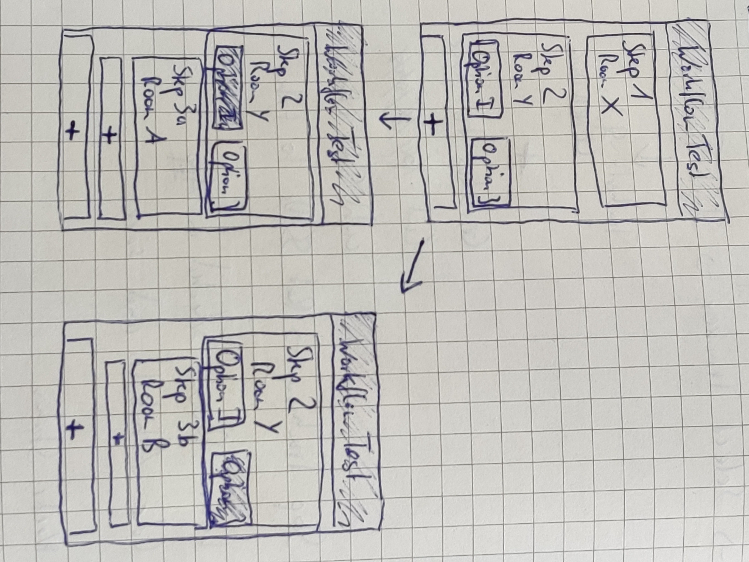
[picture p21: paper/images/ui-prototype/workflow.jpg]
	
	\centering
	\caption{Design-Prototyp der Darstellung von Workflows}
	\label{fig:ui-workflow}
\end{figure}

\subsubsection{Detailseite für Tracker} \label{sec:app-room}
In \autoref{fig:ui-detail-page} ist der Design-Prototyp für eine Detailseite dargestellt.
Beispielhaft wird hier die Tracker-Detailseite behandelt.

Im Kopfbereich der Seite ist neben einem Button für die Navigation das Icon für die Klasse Tracker und der Name des Trackers dargestellt.
Der Inhaltsbereich der Seite beinhaltet eine Liste mit allen wichtigen Attributen des Trackers.
Jeder Eintrag besteht aus dem Namen des Attributs links und dem Attribut selbst rechts.
Wenn möglich soll das Attribut selbst in einem modifizierbaren Feld dargestellt werden, das vorerst gesperrt ist.

Der Fußbereich einer Detailseite besteht aus zwei Buttons.
Mit dem linken Button können die editierbaren Attribute freigeschaltet werden.
Dabei wird aus dem \enquote{Stift}-Icon ein \enquote{Speichern}-Icon und über den Button können die bearbeiteten Attribute gespeichert werden.
Der rechte Button dient zum Löschen des dargestellten Objekts.

Je nach Klasse des dargestellten Objekts ändert sich das Icon im Kopfbereich und die angezeigten Attribute.
In folgender \autoref{tab:detail-attributes} ist gelistet, für welche Klassen welche Attribute angezeigt werden und ob diese editierbar sind.

\begin{table}[]
\centering
\begin{tabular}{l|l|r}
\textbf{Klasse}  & \textbf{Attribut} & \multicolumn{1}{l}{\textbf{Editierbar}} \\ \hline
Tracker          &                   &                                         \\
								 & Label             & Ja                                      \\
								 & Raum              & Nein                                    \\
								 & Batterie          & Nein                                    \\
								 & Status            & Nein                                    \\ \hline
Raum             &                   & \multicolumn{1}{l}{}                    \\
								 & Label             & Ja                                      \\
								 & Eingelernt        & Über Button                             \\ \hline
WorkflowTemplate &                   & \multicolumn{1}{l}{}                    \\
								 & Label             & Ja                                      \\
								 & Initiale Revision & Nein                                    \\
								 & Schritte          & siehe Workflow-Darstellung              \\ \hline
WorkflowExec     &                   & \multicolumn{1}{l}{}                    \\
								 & Status            & Nein                                    \\
								 & Schritte          & Nein
\end{tabular}
\caption{Dargestellte Attribute der Klassen}
\label{tab:detail-attributes}
\end{table}

\begin{figure}[h!tbp]
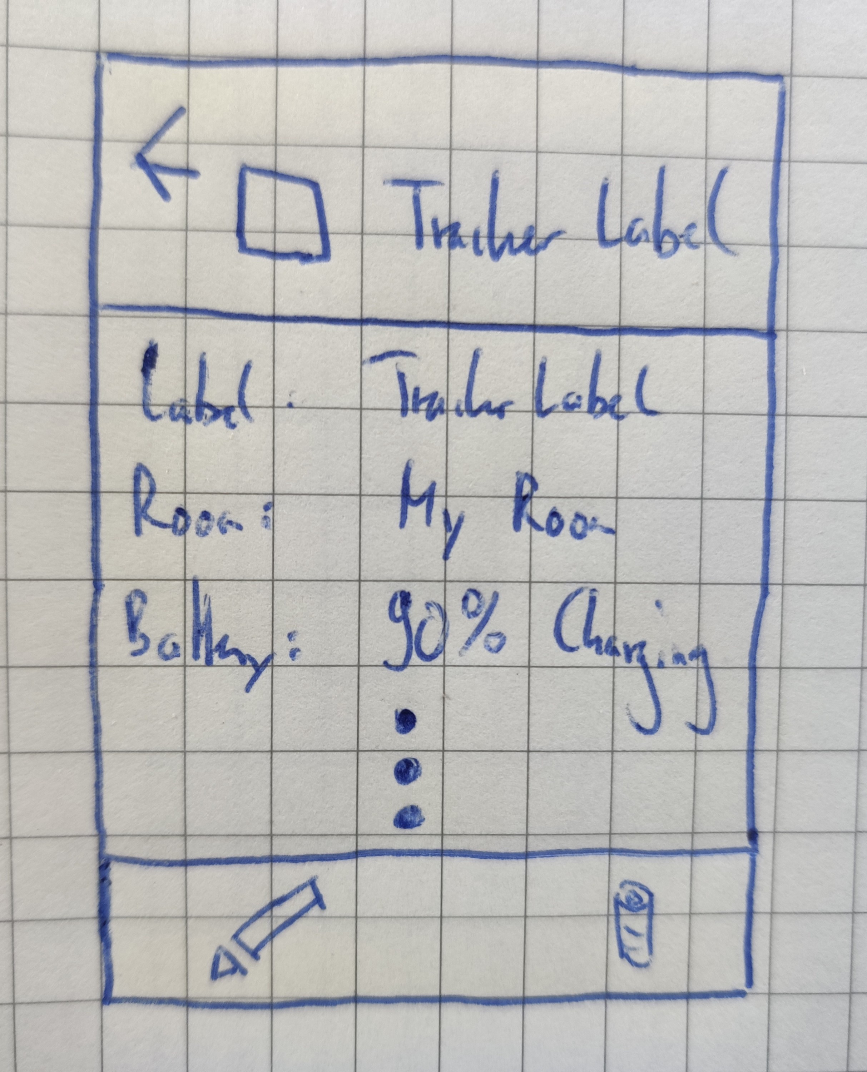
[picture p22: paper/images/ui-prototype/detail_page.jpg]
	
	\centering
	\caption{Design-Prototyp der Detailseite eines Trackers}
	\label{fig:ui-detail-page}
\end{figure}

\subsubsection{Seite zum Einlernen eines Raumes}

Weiter ist in \autoref{fig:ui-learning-page} der Protoyp der Einlern-Seite dargestellt.
Auf dieser Seite kann der Endbenutzer einen Raum einlernen.
Dazu muss in zwei Dropdowns der zu lernende Raum und der zum Lernen verwendete Tracker ausgewählt werden.
Wird von einer Detailseite eines Raumes oder Trackers auf die Lernseite navigiert, so wird dieses Objekt entsprechend in einem der Dropdowns vorausgewählt.
Sind Raum und Tracker ausgewählt, kann der Einlernvorgang gestartet werden.
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

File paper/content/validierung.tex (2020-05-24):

\chapter{Validierung}
Mit Hilfe der Validierung soll festgestellt werden, ob die gestellten Anforderungen erreicht wurden.
Besonders interessant sind im Falle des Paper-Trackers zum einen die Genauigkeit, mit der ein Tracker lokalisiert werden
kann und zum anderen, wie gut das Gesamtsystem miteinander funktioniert und bedienbar ist.
Auch das Setup eines neuen Paper-Tracker-Systems soll dabei mit berücksichtigt werden.

\section{Genauigkeitsmessung des Trackings} \label{sec:validation-tracking}
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

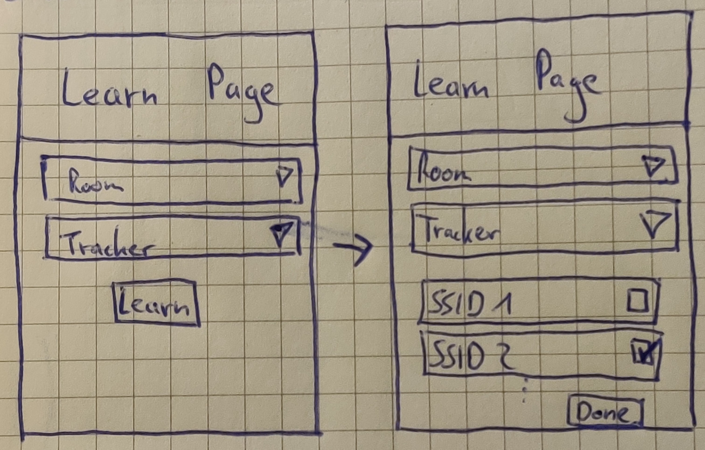
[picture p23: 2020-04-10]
paper/images/ui-prototype/learning_page.jpg

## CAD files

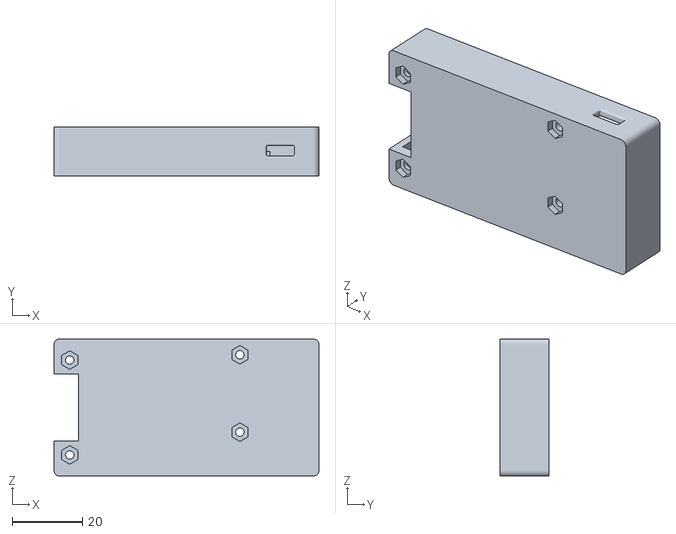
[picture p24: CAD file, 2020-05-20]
hardware/case/flat_version/case_body.stl
75.7 x 14.0 x 39.1

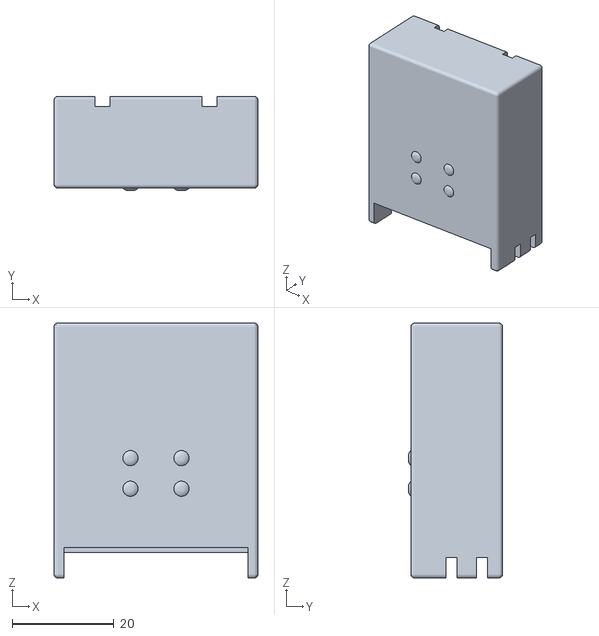
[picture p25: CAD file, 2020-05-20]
hardware/case/high_version/case_body.stl
40.0 x 18.5 x 50.0

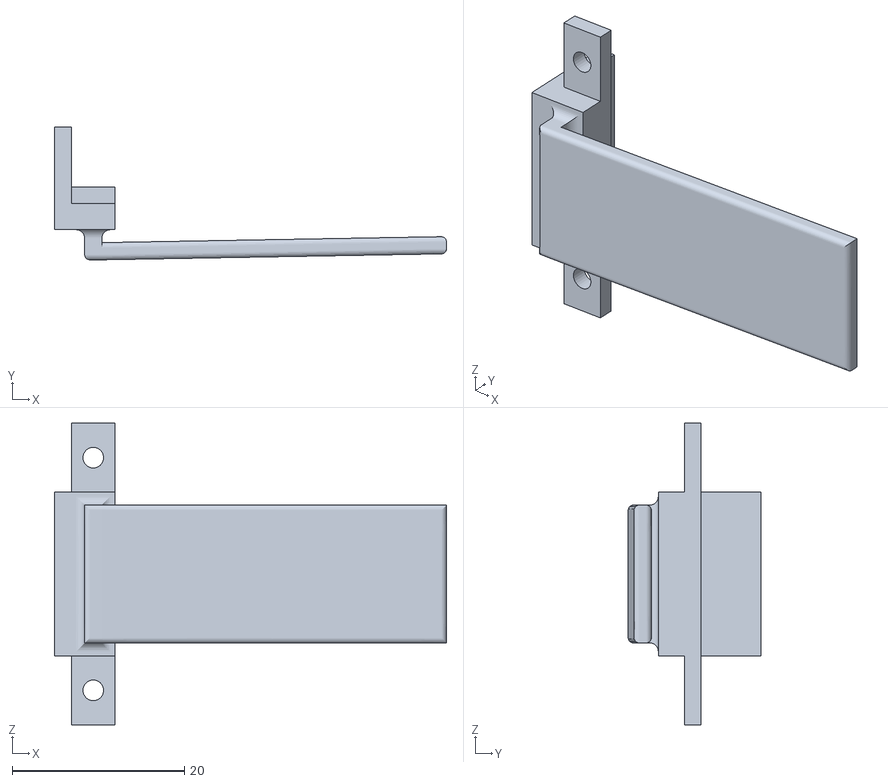
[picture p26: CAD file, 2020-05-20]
hardware/case/flat_version/clip.stl
45.5 x 15.4 x 35.0

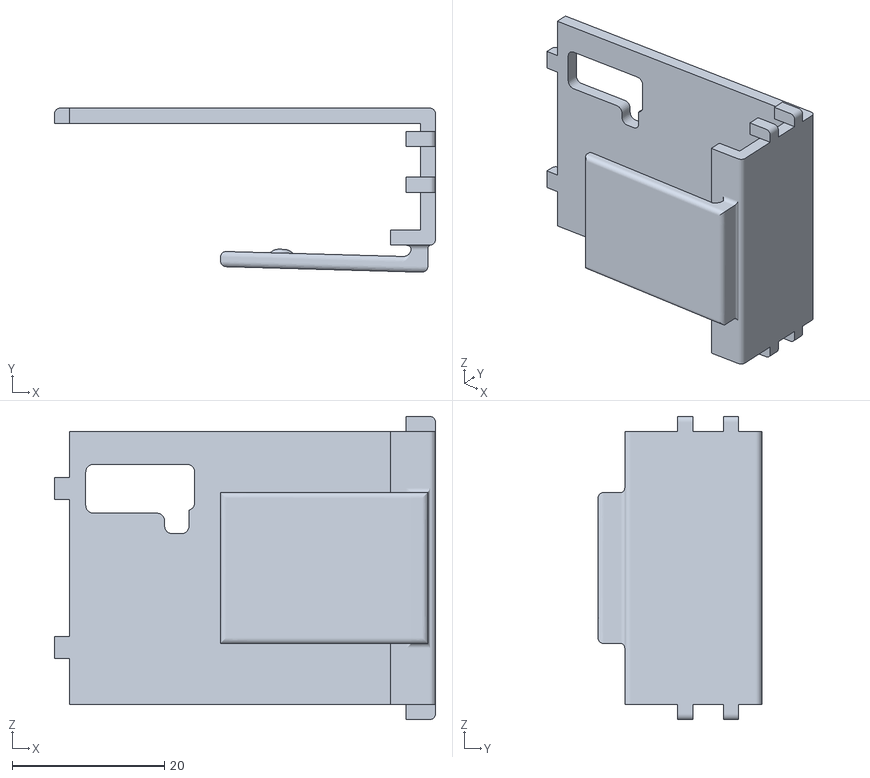
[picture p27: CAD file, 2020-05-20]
hardware/case/high_version/case_lid.stl
50.0 x 21.5 x 39.8

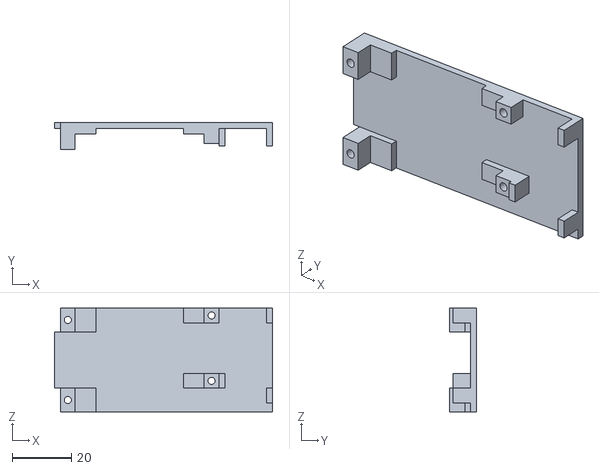
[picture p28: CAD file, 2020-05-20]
hardware/case/flat_version/case_lid.stl
73.7 x 9.00 x 35.1

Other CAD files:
hardware/case/flat_version/case_body.f3d
hardware/case/flat_version/case_lid.f3d
hardware/case/flat_version/clip.f3d
hardware/case/high_version/case_body.f3d
hardware/case/high_version/case_lid.f3d

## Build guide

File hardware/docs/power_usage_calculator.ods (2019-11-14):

ESP Batterielaufzeit
Stromverbrauch im DeepSleep [mA] | 0.1 | Wakeups/Min | 1
Stromverbrauch bei der Verbindung zum WLAN [mA] | 300 | Aktiv/Min [s] | 3
 |  | Stromverbrauch/Min [mAm] | 905.7
Wakeup-Intervall [s] | 60 | Durchschnittlicher Verbrauch [mA] | 15.095
Aktive Zeit pro Wakeup [s] | 3
Kapazität der Batterie [mAh] | 450
Geschätzte Laufzeit [h] | 29.8111957601855

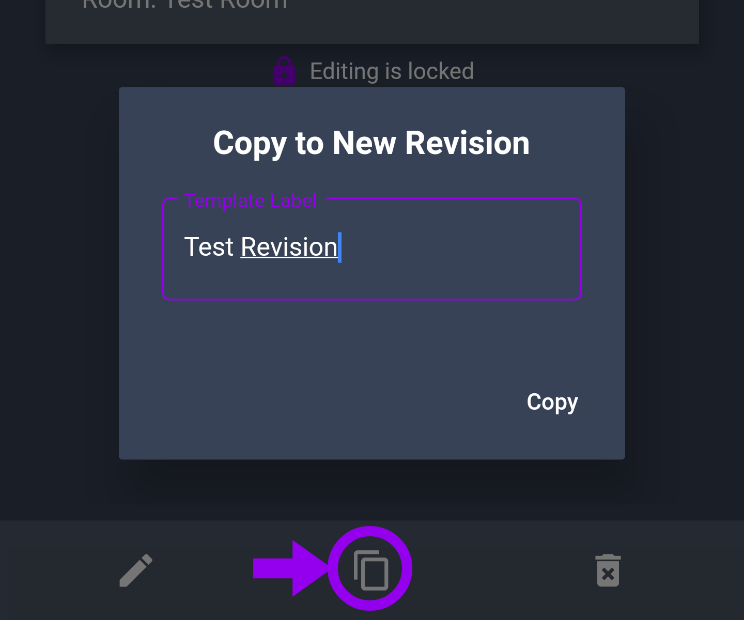
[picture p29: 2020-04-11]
app/assets/images/tutorial_11.png

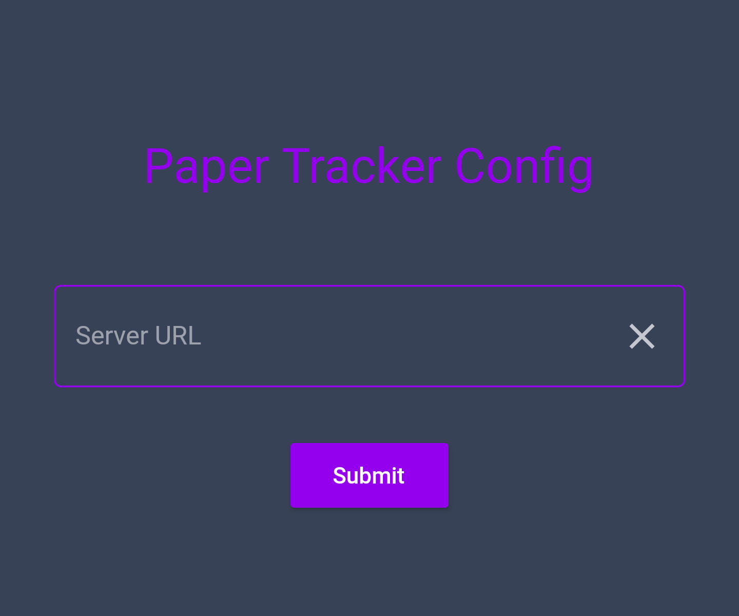
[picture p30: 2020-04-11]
app/assets/images/tutorial_1.png

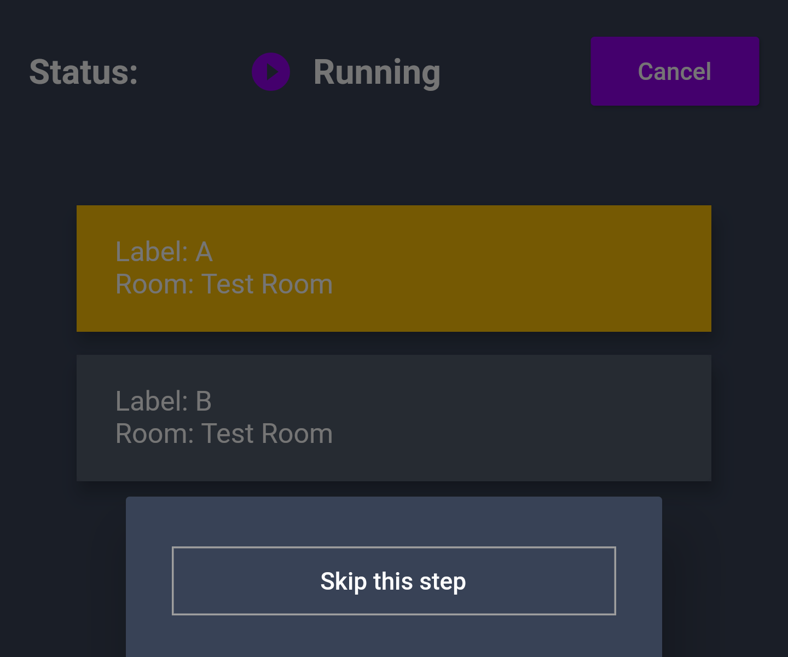
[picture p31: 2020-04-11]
app/assets/images/tutorial_13.png

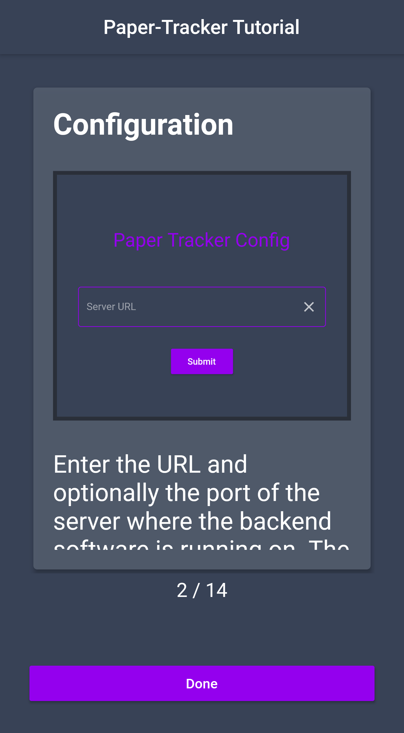
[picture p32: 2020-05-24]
paper/images/screenshot_app_tutorial_feedback.png

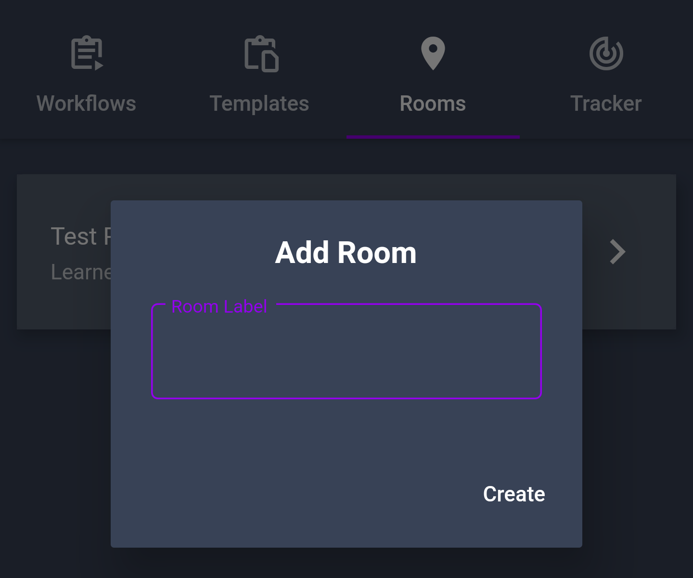
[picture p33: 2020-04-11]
app/assets/images/tutorial_6.png

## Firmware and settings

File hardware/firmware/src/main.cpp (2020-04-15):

#include <Arduino.h>
#include <WiFiUdp.h>
#include <IPAddress.h>

#include <log.hpp>
#include <models/scanResult.hpp>
#include <models/trackerResponse.hpp>
#include <models/infoResponse.hpp>
#include <serialization/cbor/CBORDocument.hpp>
#include <wifi.hpp>
#include <apiClient.hpp>
#include <power.hpp>
#include <storage.hpp>
#include <cmath>
#include <utils.hpp>

#include <credentials.hpp>

WIFI wifi;
ApiClient apiClient(&wifi.getUDP(), SERVER_IP);

void haltIf(bool condition, const char* message);
void sendScanResultsInChunks(std::vector<ScanResult>&);
void sendStatusInformation();
bool hasTrackerID();
void requestNextCommand();

static void onCommandReceived(Command& command) {
  command.print();

  switch (command.getType()) {
    case CommandType::SLEEP: {
        Power::halt_for(command.getSleepTime());
      }
      break;
    case CommandType::SEND_TRACKING_INFO: {
        auto scanResults = wifi.getAllVisibleNetworks();
        sendScanResultsInChunks(scanResults);
        Power::halt_for(command.getSleepTime());
      }
      break;
    case CommandType::SEND_INFO: {
        sendStatusInformation();
        Power::halt_for(command.getSleepTime());
      }
      break;
    default:
      // We already sleep & reset the tracker when deserializing the command, so this should never
      // be reached.
      logln("[Main] Unknown command");
  }

  requestNextCommand();
}

void setup() {
  // Initialize random source
  randomSeed(analogRead(0));
  Power::enable_powersavings();
  initSerial(115400);
  logln("[Main] Starting");

  Power::print_wakeup_reason();

  #ifndef NDEBUG
  Power::get_battery_percentage();
  Power::is_charging();
  pinMode(4, INPUT_PULLDOWN);
  auto should_clear_storage = digitalRead(4);
  if (should_clear_storage) {
    logln("[Main] Clearing storage since pin 4 is pulled high");
    Storage::clear();
  }
  #endif

  if (WIFI_USERNAME != nullptr)
    haltIf(!wifi.connect(WIFI_SSID, WIFI_USERNAME, WIFI_PASSWORD), "[Main] Failed to connect to WiFi");
  else
    haltIf(!wifi.connect(WIFI_SSID, WIFI_PASSWORD), "[Main] Failed to connect to WiFi");

  haltIf(!apiClient.start(), "[Main] Failed to start the API client");

  if (!hasTrackerID()) {
    logln("[Main] This tracker does not have an ID yet");
    apiClient.requestTrackerID([] (uint16_t newID) {
      Storage::set(Storage::TRACKER_ID, newID);
      requestNextCommand();
    });
  } else {
    requestNextCommand();
  }
}

void requestNextCommand() {
  auto id = Storage::get(Storage::TRACKER_ID);
  logf("[Main] This tracker has id %d\n", id);
  apiClient.requestNextCommand(id, onCommandReceived);
}

void loop() {
  apiClient.loop();
}

bool hasTrackerID() {
  return Storage::exists(Storage::TRACKER_ID);
}

void sendScanResultsInChunks(std::vector<ScanResult>& scanResults) {
  constexpr size_t batchSize = 10;
  uint8_t batchCount = floor(scanResults.size() / batchSize) + 1;
  uint64_t resultID = random(10, 100000);
  logf("[Main] Current resultID is %d\n", resultID);
  for (auto i = 0; i < scanResults.size(); i+=batchSize) {
    auto begin = scanResults.begin() + i;
    auto end = (i + batchSize > scanResults.size()) ? scanResults.end() : scanResults.begin() + i + batchSize;
    std::vector<ScanResult> batch(begin, end);

    auto percent = Power::get_battery_percentage();
    auto charging = Power::is_charging();
    TrackerResponse trackerResponse{percent, charging, resultID, batchCount, batch};
    CBORDocument cborDocument;
    trackerResponse.toCBOR(cborDocument);
    apiClient.writeTrackingData(Storage::get(Storage::TRACKER_ID), cborDocument.serialize(), [] () {
      logln("[Main] Sent scan results to server");
    });
  }
}

void sendStatusInformation() {
  InfoResponse infoResponse{Power::get_battery_percentage(), Power::is_charging()};
  CBORDocument cborDocument;
  infoResponse.toCBOR(cborDocument);
  apiClient.writeInfoResponse(Storage::get(Storage::TRACKER_ID), cborDocument.serialize());
}

void haltIf(bool condition, const char* message) {
  if (condition) {
    // TODO: Maybe blink the LED?
    logln("[Main] Setup action failed, stalling tracker!");
    while(true) {;}
  }
}

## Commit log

2019-10-26 Fix missing networks in JSON serialization
    For some reason, ArduinoJSON does not reserve enough size to store the
    network objects. As a workaround, we just allocate three times the
    'needed' size for the JSON object. This does not fix the issue with
    borked SSIDs yet.
2019-10-26 Simplify Log class
    Declared two macros (PRINT and PRINTLN) for calling the Serial functions
    instead of checking for NDEBUG in every method. Still keeping the
    methods for type safety.
    Also converted the class to a struct, since all methods are public
    anyways.
2019-10-26 Add runtime log, properly format WifiNetwork.print()
2019-11-11 Start switching to PlatformIO for firmware
2019-11-12 Remove old Arduino-IDE-based sources
2019-11-13 Hardware: Add documentation for serialization and power usage
    [power_usage_calculator.ods]
2019-11-19 Add unit test and mocking framework, try out in tracker_manager_t… (#11)
    * Add interfaces for repositories
    * Add unit test and mocking framework, try out in tracker_manager_test
2019-11-19 Start implementing CoAP, add CI (#10)
    * Hardware: Work on coap implementation
    * Hardware: Add TinyPICO build target
    * Hardware: Remove ArduinoJSON
    * Hardware: Remove CBOR
    * Hardware: Make log.h templated
    * Hardware: Work on CoAP implementation
    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
2019-11-21 Hardware: Issue a get request to backend
    [main.cpp]
2019-11-21 App: Add example test for tracker (de)serialization, add Makefile (#13)
    * App: Add example test for tracker (de)serialization, add Makefile
    * Use default flutter in Makefile
2019-11-26 Implement endpoints and a manager to handle learning rooms (#21)
    * Add improved uml diagram
    * Start implementing learning functionality
    * Add goroutine to add tracking requests for learning
    * Extract creating tracker cmds
    * Refactor dir structure
    * Add scanResultRep, implement inserting trackingData from tracker for learning
    * Add tests for NewTrackingData
    * Add room rep and manager
    * Add ep to get all rooms
    * Add finishLearning to trackerManager
    * Refactor managers, add getLearningStatus
    * Add tests for getLearningStatus
    * Add missing mock return
    * Changes from PR
2019-11-26 Add basic layouting for the app (#24)
    * Start working on proper layout
    * Start working on proper layout
    * Add example of add floating action button
2019-11-27 App: Implement basic room detail page (#28)
    * Add room page, further style everything accordingly
    * Add editing/save button
    * Add basic room attribute overview
2019-12-02 Hardware: Add power saving measures
2019-12-03 App: Add learn page with dropdowns, start button and countdown ti… (#35)
    * Add page with dropdowns for learning rooms
    * Play around with styling via themes
    * Delete scan results for tracker before learning
    * In app tracker client add learning, change json keys
    * Add countdown indicator when learning room
    * Add text to countdown
    * Fix app json tests
    * Fix failing go test
2020-01-05 Hardware: Fix callbacks into main.cpp
    The issue was a wrong capture on a lambda method.
    This closes #34
    [main.cpp]
2020-02-02 Hardware: Sending scan results works!
    🎉
2020-02-20 App: Add buttons to add workflow steps
2020-02-20 App: Add button to add decision
2020-02-25 Hardware: Fix CBOR field names, finalize tracker IDs
    [main.cpp]
2020-02-25 App/Server: Add tracker battery
2020-02-25 Hardware: Send battery percentage
2020-02-25 Hardware: Send charging state to server
2020-02-25 Hardware: Send charging status and battery percentage
2020-02-26 Server: Don't send battery stuff via CBOR to tracker
2020-02-26 App: Add cancel learning button, small improvements
2020-03-03 App: Add cancel button to exec page
2020-03-09 App: Add button to create template revision
2020-03-10 App: Use button for firstRevision
2020-03-11 App: Use proper ID for getting current exec step
2020-03-11 App: Remove conditional builder for getting current step of exec
2020-03-26 Paper: Write about battery
2020-04-02 Hardware: Fix battery percentage calculation
    [main.cpp]
2020-04-03 Server: Add new command to send battery information
2020-04-03 Hardware: Add new command to send battery information
2020-04-03 Server: Store last battery status update time for tracker
2020-04-03 Hardware: Fix bugs with battery updates
    [main.cpp]
2020-04-03 App: When learning wait for next poll before starting learn timer
2020-04-05 Hardware: Fix break statement, indentation
    [main.cpp]
2020-04-07 Paper: Add more app prototypes
2020-04-08 Paper: More UI Prototype
2020-04-09 Flasher: Better IP replacement
    [main.cpp]
2020-04-11 Hardware: Fix callback timeouts
    Also started to improve logging by adding a tag to each log line,
    indicating where the log originates from.
    This fixes #134.
    [main.cpp]
2020-04-14 Server: Add orig revision sheet for export
    [export.xlsx]
2020-04-14 Server: Add some comments to exportManager
    [export.xlsx]
2020-04-14 Meta: Add pictures of TinyPICO with battery
2020-04-15 Hardware: New API for halting (Power::halt_for)
2020-04-15 Hardware: Clamp battery percentage to 0%
    This closes #127
2020-04-16 Server: Send notifiation email for low battery
2020-04-17 Paper: Mostly case stuff
2020-04-22 Paper: HTTP-API-Tabelle gefixed, REST-Quelle
    Die Tabelle hat jetzt Zwischenüberschriften, eine Caption (ist damit
    auch im Tabellenverzeichnis) und die Abkürzung in der Tabelle ist raus
    (wf für Workflow).
    Ansonsten habe ich noch Fieldings Dissertation für REST als Quelle
    hinzugefügt.
2020-04-26 Flasher: Switch to 7zip for archive creation
    We do this since 7zip is available on both Windows and Linux runners on
    Github actions.
2020-05-19 HW: Add case files for Fusion 360
    [case_body.f3d, case_lid.f3d, clip.f3d]
2020-05-19 HW: Add stl files
    [case_body.stl, case_lid.stl, clip.stl]
2020-05-20 Paper: Write about battery reading
2020-05-21 Paper: Add more options for battery measurement problems
2020-05-22 Paper: Write about battery runtime measurements
